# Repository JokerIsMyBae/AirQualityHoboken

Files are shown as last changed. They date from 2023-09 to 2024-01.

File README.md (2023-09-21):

# AirQualityHoboken
Applied IoT project voor luchtkwaliteitsmetingen in Hobokense Polder

### Doel
Meten van specifieke luchtkwaliteitsparameters:
- CO2
- TVOC
- NOx
- Fijnstof
- Temperatuur
- Luchtvochtigheid
- Luchtdruk

### To-Do:
- Bouwen van een sensorbord
- Meten van specifieke luchtkwaliteitsparameters
- Werkt op batterij & PV-cel
- Locatie via GPS
- PCB
- Communicatie via LoRaWAN
- Langdurige test op statische plaatsen Hoboken
- Data opslagen in een DB

### Deliverables
- Robuuste werkende schakeling
- Versie voor Hoboken / light-weight autonome versie voor PoAB
- Sensorbord, modulair, met LoRaWAN module
- 2 testversies op de campus
- 10 definitieve versies

### Deliverables
- Implementatie in Hoboken op statische plaatsen
- Implementatie in de haven op statische plaatsen
- Implementatie in op een drone
- Communicatie via LoRaWAN
- Visualisatie van data via NodeRed - Grafana
- PCB
- Documentatie
- Film

References:
- Power delivery (DFRobot + solar panels)
  https://github.com/Verbeast2K/zanzi-doc/tree/master/sensorbox
- Other parts
  https://github.com/Jappie3/zanzi-doc

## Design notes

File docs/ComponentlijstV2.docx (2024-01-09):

Componentenlijst

benodigdheden voor Lucht kwaliteit meting Hoboken

Component | # nummer | Link | Aantal
LoRa Chip | esp32 | SX1276 | https://jlcpcb.com/partdetail/Dreamlnk-DL_RFM95868M/C2844472 | 5
Esp32 MCU | ESP32-WROOM-32-N8 | https://jlcpcb.com/partdetail/EspressifSystems-ESP32_WROOM_32N8/C529582 | 5
Voltage regulator | LD1117S33TR | https://jlcpcb.com/partdetail/Stmicroelectronics-LD1117S33TR/C86781 | 5
USB --> UART | CP2102N | https://jlcpcb.com/parts/componentSearch?searchTxt=CP2102N | 5
UFL - connector | 0734120110 | https://www.digikey.be/en/products/detail/molex/0734120110/1894611 | 5
Antenne LoRa 868MHz | | https://www.digikey.be/nl/products/detail/pycom-ltd./SIGFOX%2FLORA%2520ANTENNA%2520KIT/7721843?productid=7721843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 | 5
Zonnepaneel | 110X80 | Aanwezig op school | 10
Solar power manager | DF robot | DFR0559 | https://www.dfrobot.com/product-1712.html + stand offs | 5
Batterij 3,7V | 45F2232 | https://www.sossolutions.nl/lithium-ion-batterij-3-7v-1200mah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 | 5
Kabel – 2 draads | (E1052S.41.10) EN50306-3-RAIL-2X0.75 | (https://www.digikey.be/nl/products/detail/prysmian-group/E1052S-41-10/618558) https://www.digikey.be/nl/products/detail/te-connectivity-raychem-cable-protection/EN50306-3-RAIL-2X0-75/13590732 | 2m
Milieu sensor | SEN55 | https://www.sensirion.com/products/catalog/SEN55 | 5
JST connector SEN55 | BM06B-GHS-TBT | https://www.digikey.nl/nl/products/detail/jst-sales-america-inc/BM06B-GHS-TBT-LF-SN-N/807850 https://jlcpcb.com/partdetail/207057-BM06B_GHS_TBT_LF_SN_N/C189892 | 5
Stikstof sensor | SGP41 | https://sensirion.com/products/catalog/SGP41 https://jlcpcb.com/partdetail/Sensirion-SGP41_DR4/C9900005629 | 5
JST connectie kabel | JST GH6 | https://www.adafruit.com/product/5754 | 5
Wartel (voor zonnepaneel kabel) | 12002100 | https://be.farnell.com/bopla/12002100/metric-cable-gland-mbf-m12-x-1/dp/3216813 | 5
Installatie doos | Z74H | https://www.tinytronics.nl/shop/en/tools-and-mounting/enclosures/universal/kradex-enclosure-176x126x57mm-ip65-red-transparent-z74h | 5
Backplate | | Zelf maken | 5
Standoffs | | | 40
Testboard | ESP32-dev-board | https://www.tinytronics.nl/shop/en/development-boards/microcontroller-boards/with-wi-fi/esp32-wifi-and-bluetooth-board-cp2102

Legende:

- PCB
- Voeding
- Behuizing
- Sensoren

Nog te bestellen:

- 4X SEN55
- 5X SEN55 JST connectie kabel
- 5X Wartel
- 2m Kabel – 2 draad
- 4 X behuizing

# Gateway

https://github.com/Jappie3/zanzi-doc/blob/master/gateway/BOM.md

The gateway board uses a CM4-POE-UPS-BASE KIT board as base with a Raspberry PI 4 Compute module. This board has a buildin UPS which uses 3 18650 Li-ion batteries, furthermore the board can be powered from POE (802.3af).

BOM

CM4-POE-UPS-BASE KIT (https://www.waveshare.com/wiki/CM4-POE-UPS-BASE)

3X 18650 batteries

Raspberry PI Compute module 4 with 32GB MMC (CM4104032) (https://datasheets.raspberrypi.com/cm4/cm4-product-brief.pdf)

Antennas voor LoRaWAN

2x Pigtail SMA-MHF

CR2032 batterij

USB SDR + antenna

IC880A LoRaWAN board (https://wireless-solutions.de/products/lora-solutions-by-imst/radio-modules/ic880a-spi/)

Adapter bord IC880A (see below)

Metal housing (https://benl.rs-online.com/web/p/wall-boxes/7755808)

Metal Housing adapter, lasercut from custom design housing_adapter.dxf (https://github.com/Verbeast2K/zanzi-doc/blob/master/gateway/housing_adapter.dxf)

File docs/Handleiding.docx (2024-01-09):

# Handleiding: Hobokense Polder luchtkwaliteit dashboard

# Inleiding

Hieronder vind je de handleiding hoe je het dashboard van de Hobokense Polder kan gebruiken. Als dashboard platform gebruiken we Grafana deze is toegankelijk op de volgende URL: http://npunt.iot-ap.be/. Deze website is beveiligd met een account.

# Kennismaking Grafana

Als je voor het eerst naar http://npunt.iot-ap.be/ surft zal hij jou voor gebruikers gegevens vragen, Vul deze in

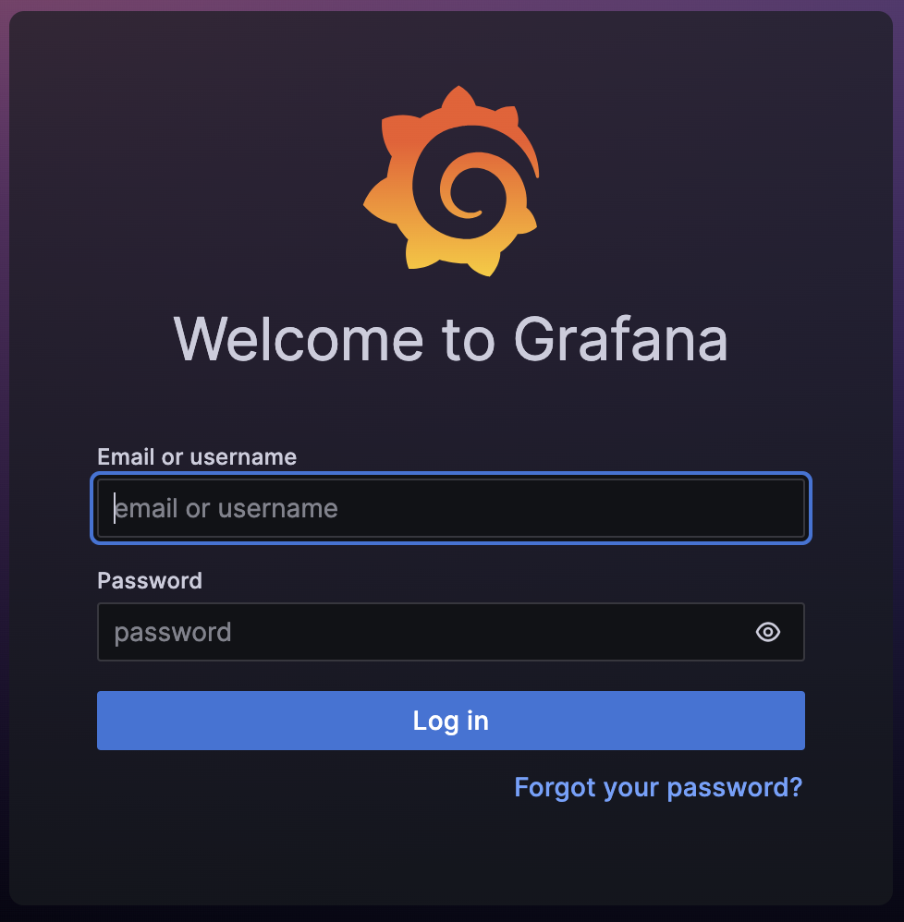
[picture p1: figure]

Dan zal je naar de hoofdpagina van Grafana gestuurd worden. Selecteer hier het dashboard “Hobokense Polder”.

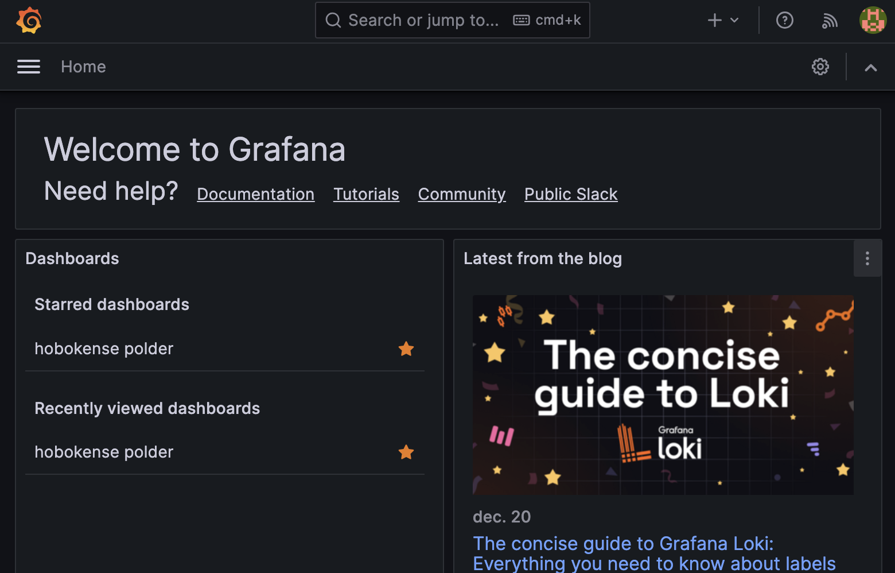
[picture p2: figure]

## Dashboard

A)

B)

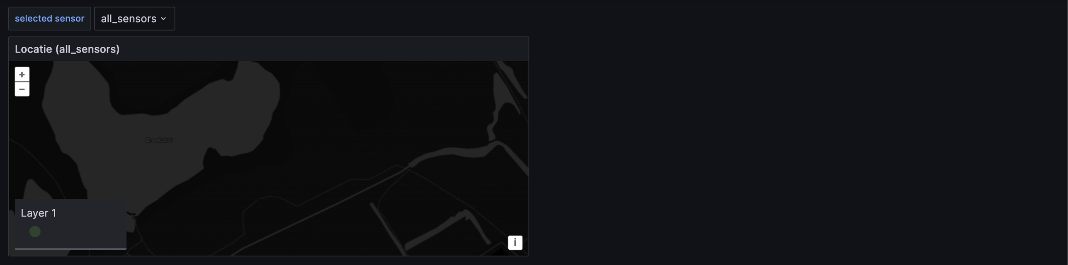
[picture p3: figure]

C)

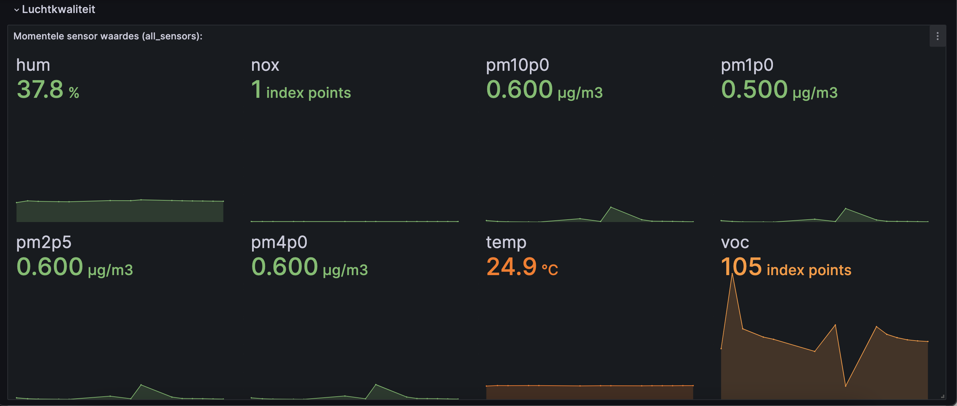
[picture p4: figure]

D)

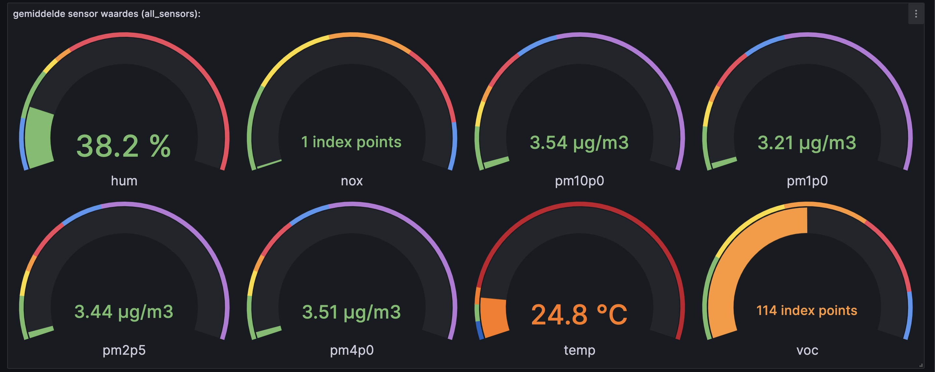
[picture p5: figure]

E)

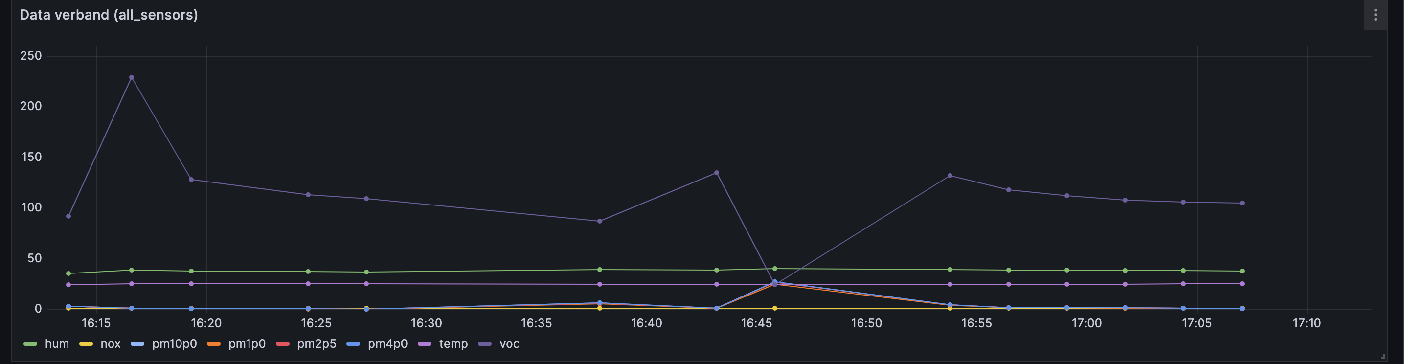
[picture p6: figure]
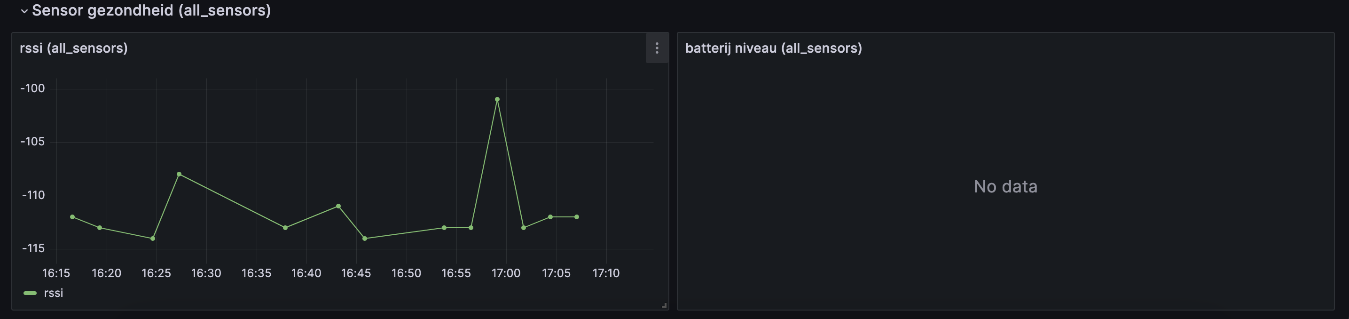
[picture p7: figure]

G)

F)

Uitleg panelen:

a) Linksboven zie je een drop down menu waaruit je kan kiezen welk sensor je wilt gaan bestuderen (dit zijn alle sensoren die zich in de database bevinden) ook kan je de optie “all_sensors” kiezen, het gehele dashboard zal aangepast worden aan de waarde van jouw keuze.
b) Ook vind je van boven een kaart terug, deze geeft de locatie van de sensor weer (of in het geval van “all_sensor” keuze geeft deze alle locaties weer van alle sensoren). De locatie wordt gekozen afhankelijk van welke statisch locatie je hebt opgegeven in de thethingsnetwork op de sensor. (Applications > AirQualityHoboken > End Device > (sensor) > location

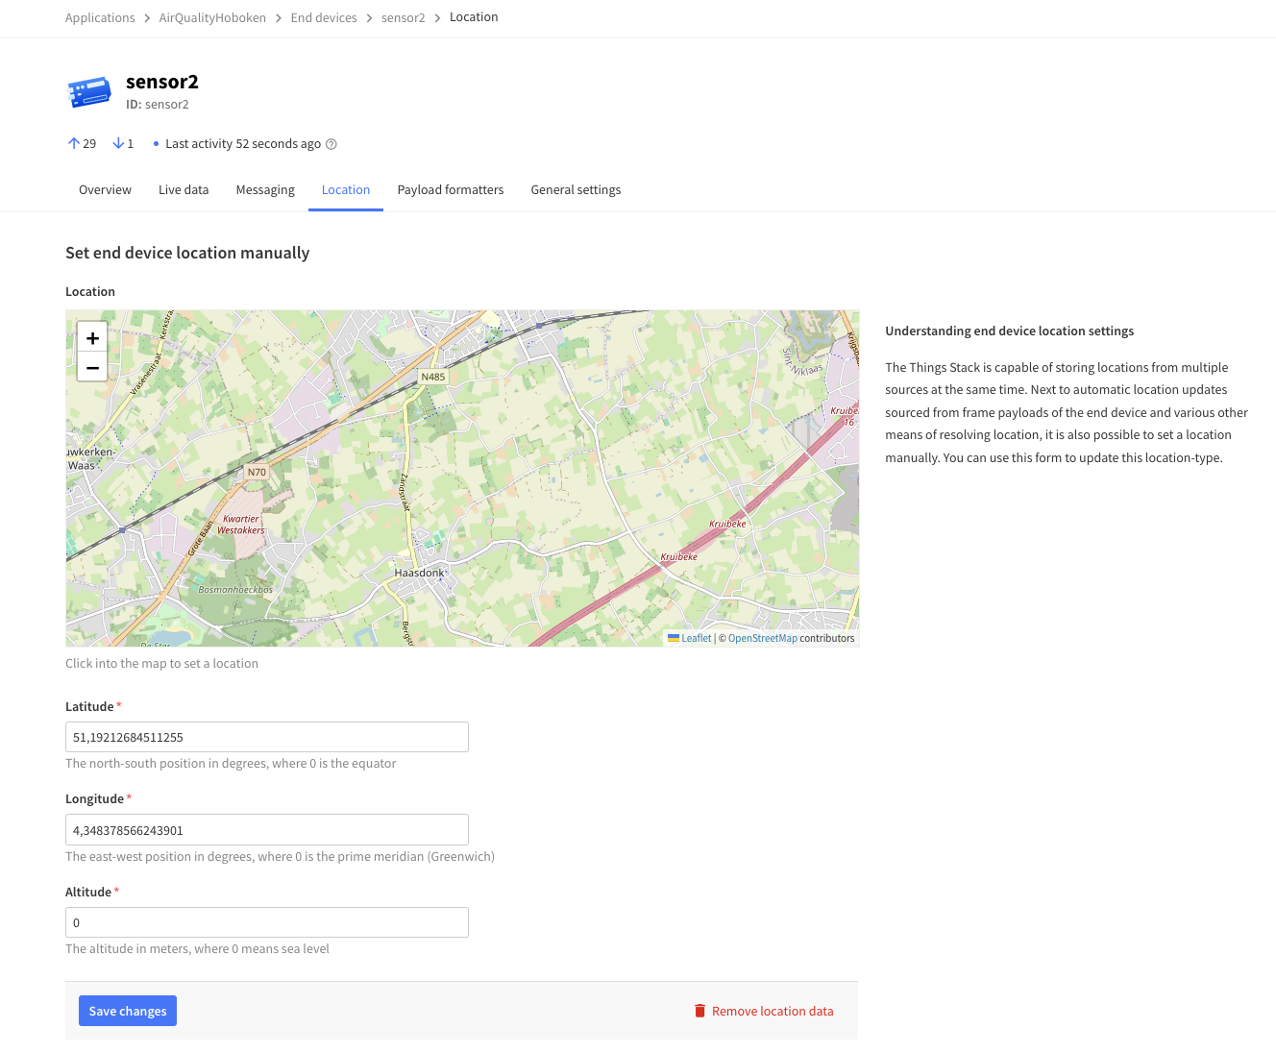
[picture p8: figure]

c) Dit paneel met grafiek geeft de laatste actuele sensor waarde weer van elke sensor ook geeft deze een kleine history weer (deze history is afhankelijk van welke time range je hebt opgegeven).

De time range kan je helemaal boven aan aanpassen

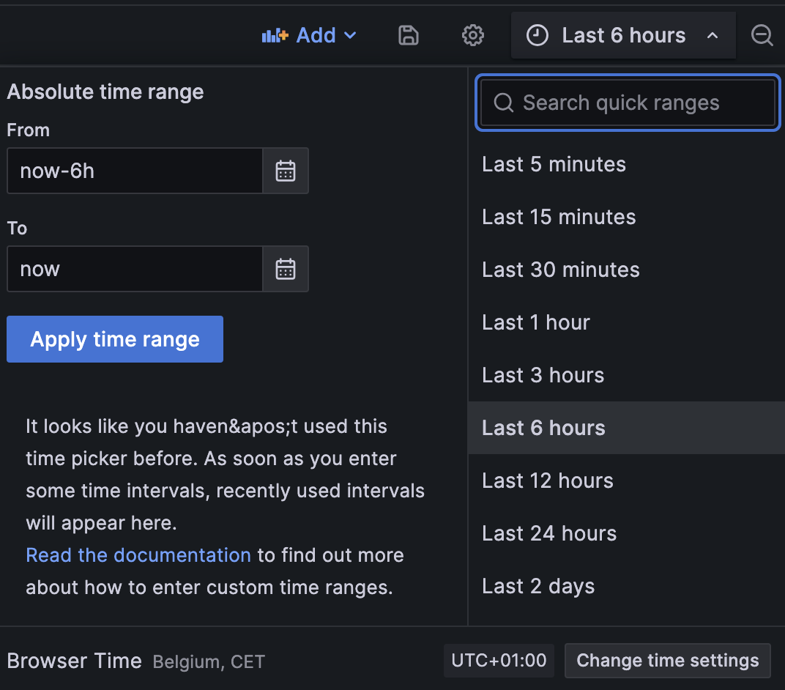
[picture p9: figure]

d) Dit paneel geeft de gemiddelde sensor waardes weer af alle data die zich in de timeline bevindt. Dit betekent dus als je gemiddelde tempratuur wilt weten van de afgelopen 24h stel je de timeline in op “last 24 hours”.

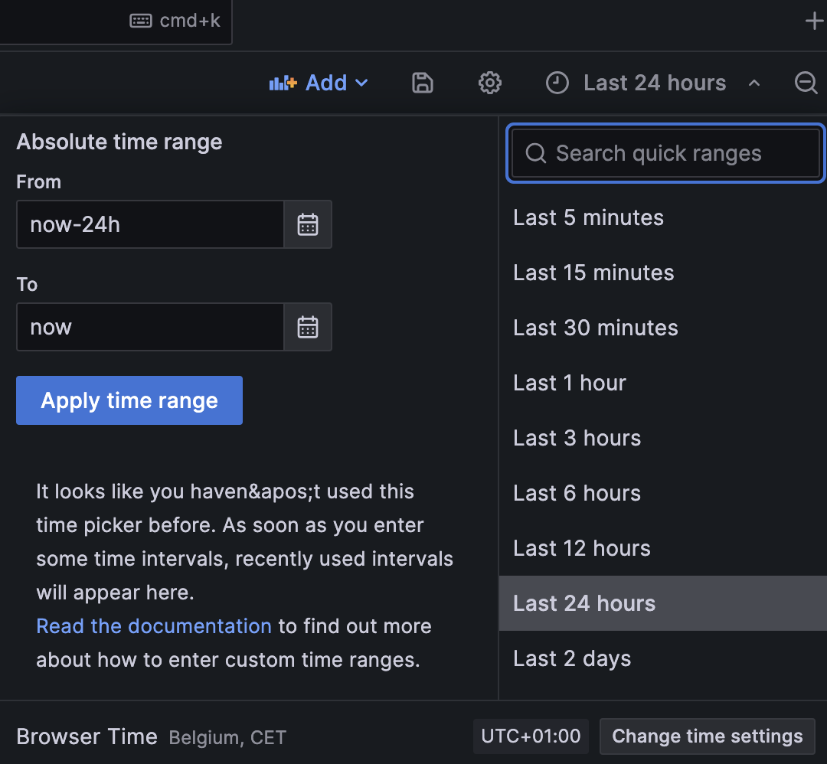
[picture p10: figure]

e) In dit paneel kan je de verbanden tussen verschillende sensor waardes weergeven. Ook hier is deze timeline afhankelijk
f) Dit paneel geeft een grafiek weer over de rssi, met andere woorden hoe sterk de verbinding is tussen sensor kast en LoraWan-gateway. Hoe lager dit getal bij 0 zit hoe beter. Deze geeft dus geen informatie weer over de luchtkwaliteit. Ook hier is deze timeline afhankelijk.
g) Dit paneel geeft de batterij capaciteit weer van de sensor kast. Door tijdsgebrek is deze functie op de sensor kast niet afgeraakt.

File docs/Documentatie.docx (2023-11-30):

# Documentatie

# Hardware | sensoren & PCB

## Sensoren | SEN55 & SPG 41

### SEN55:

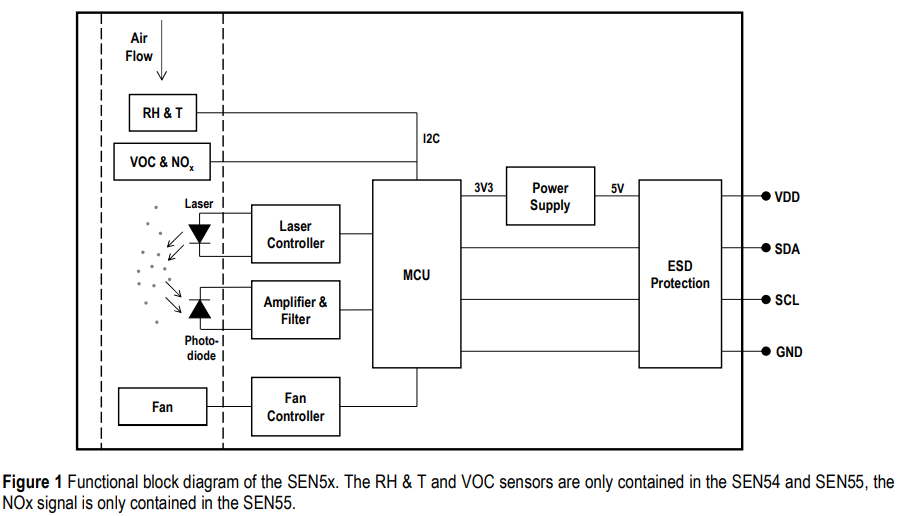
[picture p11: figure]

De SEN55 is een eenvoudig, alles-in-één platform voor sensoroplossingen voor het nauwkeurig meten van verschillende omgevingsparameters, zoals fijnstof, vluchtige organische stoffen (VOC's), oxiderende gassen, zoals stikstofoxiden (NOx), en als vochtigheid en temperatuur.

Over het algemeen kunnen de meeteenheden als volgt zijn:

- Fijnstof: Gemeten in microgram per kubieke meter (µg/m³) voor de concentratie van fijnstofdeeltjes in de lucht.
- VOC's: Gemeten in ppb (parts per billion) of ppm (parts per million) voor de concentratie van vluchtige organische stoffen in de lucht.
- NOx: Gemeten in ppb of ppm voor de concentratie van stikstofoxiden (NOx) in de lucht.
- Vochtigheid: Gemeten in procent (%), wat de relatieve luchtvochtigheid weergeeft.
- Temperatuur: Gemeten in graden Celsius (°C) voor de temperatuur in de omgeving.

De exacte eenheden en meetbereiken kunnen variëren afhankelijk van de specifieke sensoren en configuraties die worden gebruikt binnen het SEN55-platform van Sensirion.

### SPG 41:

De SGP41 is een VOC- en NOx-sensor van Sensirion. Deze sensor is zeer geschikt voor het voortdurend monitoren van de VOC- en NOx-situatie, inclusief potentieel schadelijke gebeurtenissen die niet door mensen worden waargenomen.

De meeteenheid voor VOC kan in het algemeen worden uitgedrukt in parts per billion (ppb) of parts per million (ppm), afhankelijk van de concentratie van vluchtige organische stoffen. NOx-concentraties worden meestal uitgedrukt in ppb of ppm voor gassen zoals stikstofdioxide (NO2) en stikstofmonoxide (NO). De precieze meeteenheden kunnen variëren afhankelijk van de specifieke configuratie en toepassing van de sensor.

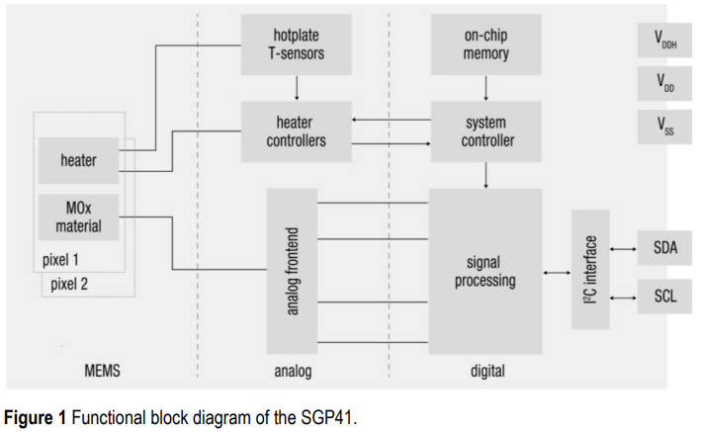
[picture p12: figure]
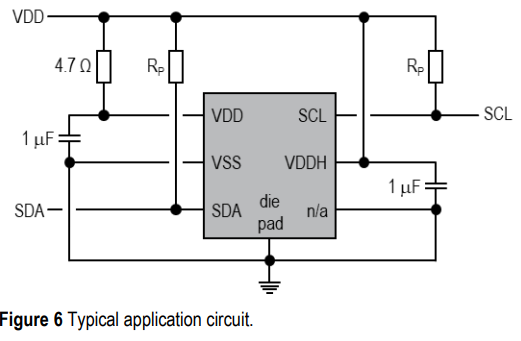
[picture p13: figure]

## PCB

### 1ste versie

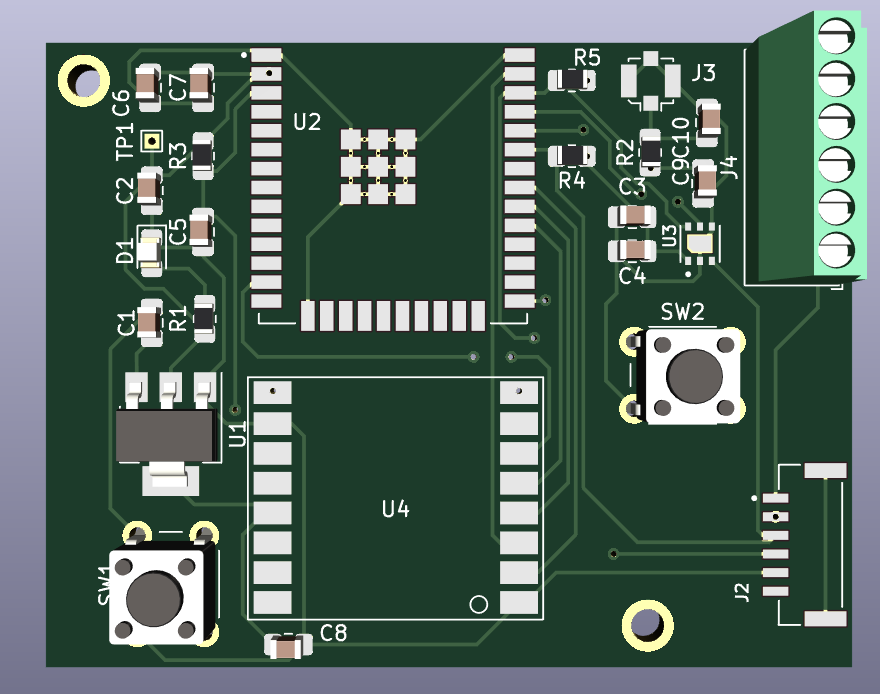
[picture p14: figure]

Front

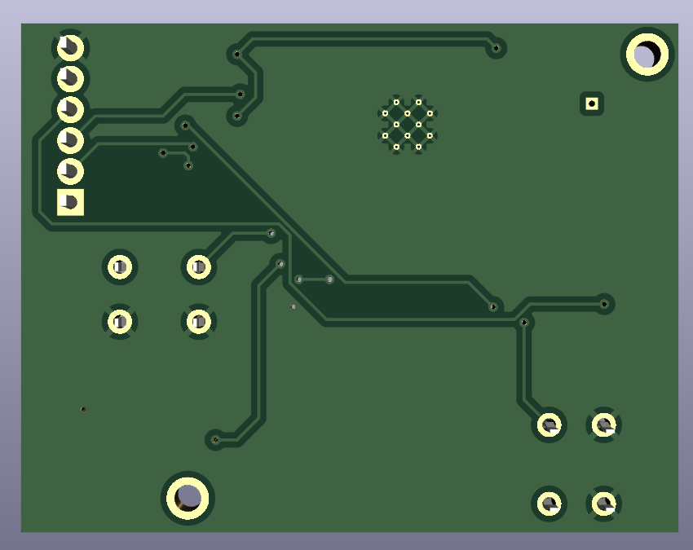
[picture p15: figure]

Back

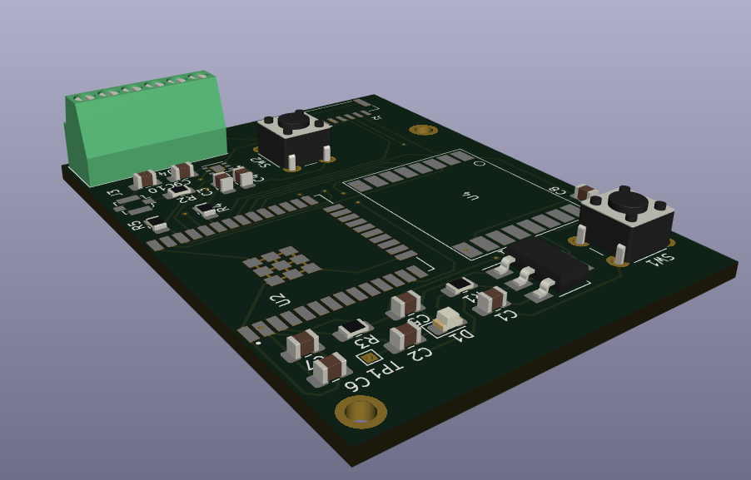
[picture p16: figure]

Isometrische projectie

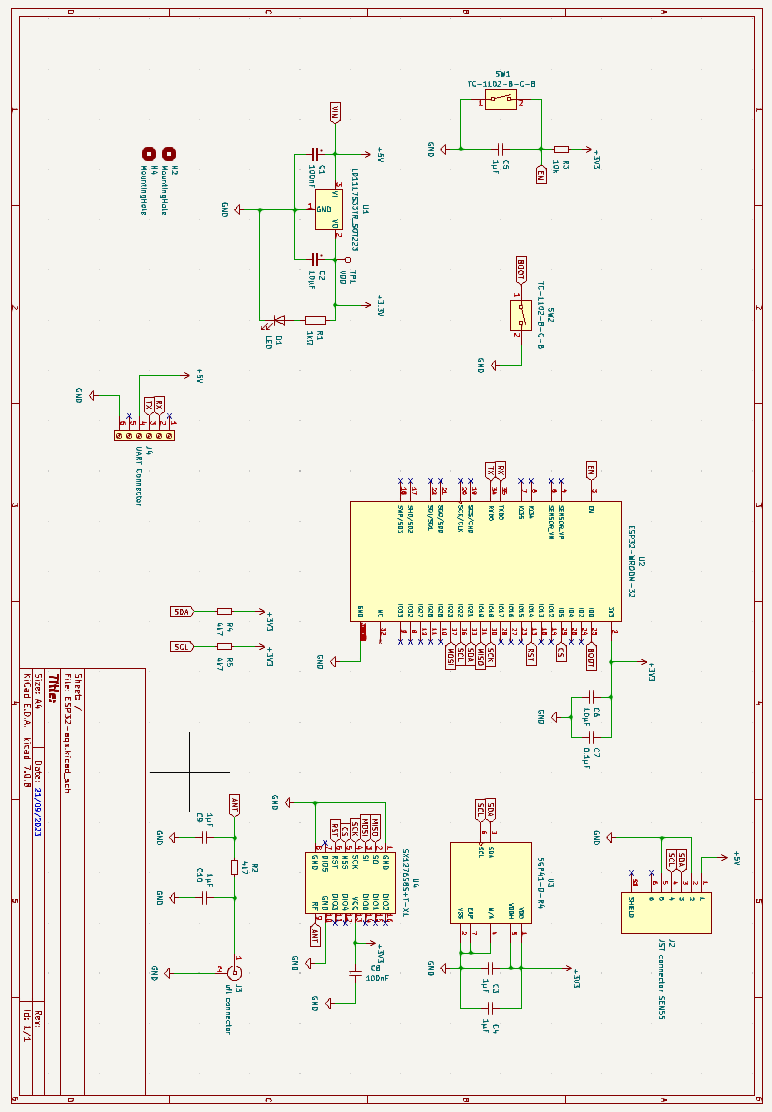
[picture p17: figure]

Uitleg pcb:

We dienden rekening te houden met verschillende aspecten, waaronder de dikte van onze PCB-lijnen in relatie tot het stroomverbruik. We hebben eerst het maximale stroomverbruik berekend en deze verdubbeld. Met behulp van een PCB Trace Width Calculator hebben we parameters zoals stroomverbruik, normale temperatuur, stijgende temperatuur en dikte ingevoerd. Uit de berekeningen bleek dat de lijndikte minimaal 0.03 mm moest zijn. De standaarddikte die we in KiCad gebruiken is 0.25 mm, wat ruim voldoende is.

Bij de plaatsing van de ESP32-chip moesten we ervoor zorgen dat de antenne niet tussen andere componenten lag. Dit hebben we opgelost door de antenne iets buiten het bord te laten steken. Daarnaast was het belangrijk om ervoor te zorgen dat de connectoren aan de zijkant waren geplaatst om een optimale verbinding te garanderen.

BoM

# Layout en design (enclosure)

Backplate:

Aangezien we alles gemakkelijk willen monteren hebben we gekozen om een backplate te monteren in onze installatie doos. Dit maakt zo wel ontwikkeling en installatie handiger. Alle componenten worden individueel gemonteerd op deze backplate doormiddel van standoffs:

- PCB
- Antenne
- Batterij
- SEN55 (temp, hum, VOc, NOc, fijnstof sensor)

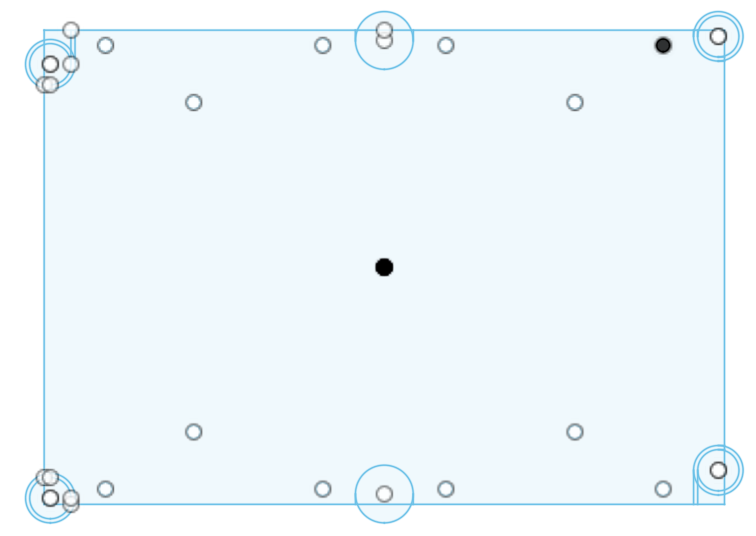
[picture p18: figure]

## Dak:

Aangezien vandalisme en het verstoren van de natuurlijk een belangrijk topic is voor natuurpunt. Hebben we dus beslist om de sensoren op een bepaalde hoogte te hangen (bijvoorbeeld in een boom). Aangezien we niet een lelijke installatie doos in een boom willen hangen willen we deze dus camoufleren in de natuur, hierdoor hebben we gekozen om de installatie doos meer te doen lijken op een nestkastje. Dit gaan we doen door een 3D print te ontwikkelen die als punt dak zal gemonteerd worden op de bovenkant van de installatie doos. Voordeel hiervan is dat we ook een plaats hebben om onze zonnepanelen te monteren.

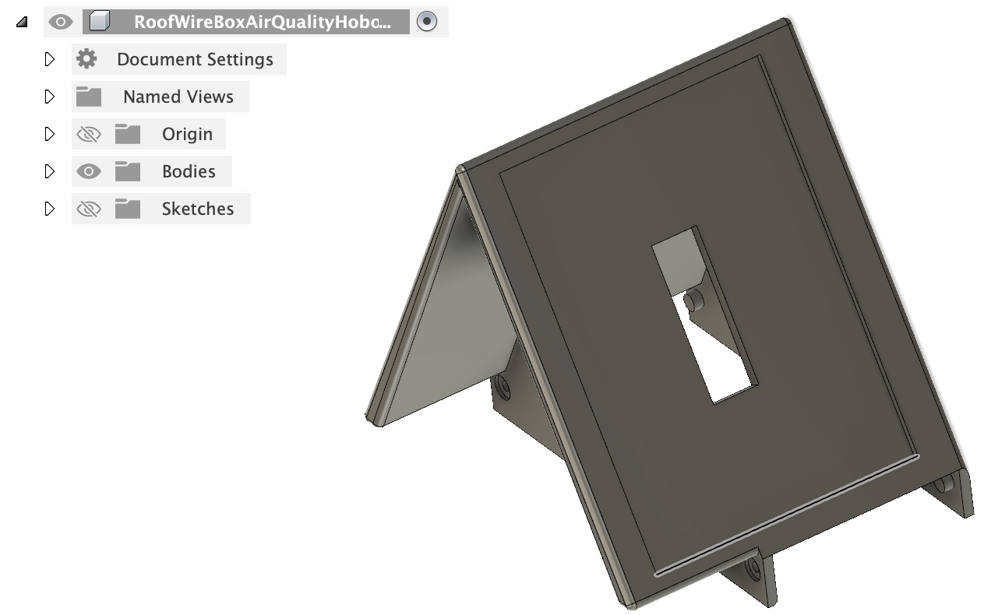
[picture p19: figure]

# TheThingsNetwork | LoRaWAN

## TheThingsNetwork

### Wat is de TheThingsNetwork:

TheThingsNetwork (TTN) is een open source en door de gemeenschap gedreven project dat tot doel heeft een wereldwijd, crowd-sourced en gedecentraliseerd Internet of Things (IoT)-netwerk te creëren. Het biedt de infrastructuur en tools die nodig zijn om een LoRaWAN (Long Range Wide Area Network) voor IoT-apparaten te bouwen en te exploiteren. TTN is gebaseerd op LoRaWAN-technologie en wordt onderhouden door vrijwilligers en gemeenschappen. Het stelt bedrijven en ontwikkelaars in staat om IoT-oplossingen te bouwen boven op dit netwerk.

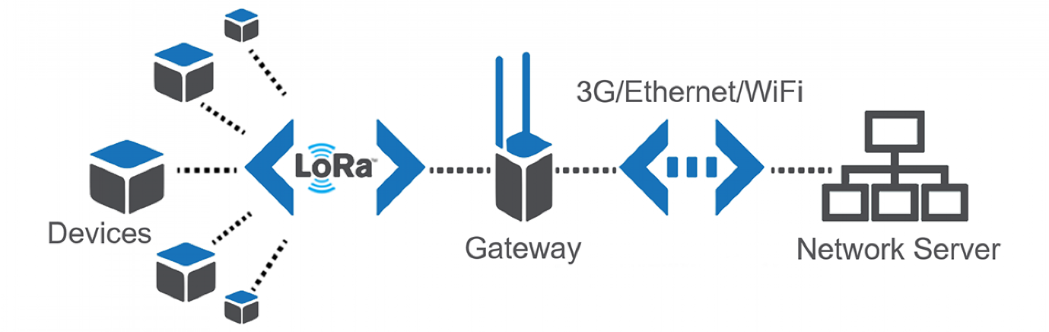
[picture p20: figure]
LoraWan | antennas and accessories

Figuur 1 Data overdracht sensor naar TTN

### Hoe werkt TTN:

Na het creëren van een end device en het genereren van de unieke sleutels en ID, volgt het volgende proces:

End Device Communicatie: Het end device, zoals een IoT-sensor of -apparaat, verzendt gegevens die het wil overdragen via het LoRaWAN-protocol.

Data Verpakt: De gegevens worden verpakt in LoRaWAN-pakketten, die de ID van het end device bevatten, evenals de beveiligingssleutels die nodig zijn voor de codering en beveiliging van de gegevens.

Verzending naar de Gateway: De LoRaWAN-pakketten worden via radiofrequentie verzonden naar een nabijgelegen gateway, die fungeert als een ontvangststation. Gateways kunnen overal in de omgeving zijn geïnstalleerd en kunnen de gegevens van meerdere end devices ontvangen.

Gateway naar Netwerk Server: De gateway ontvangt de pakketten, decodeert de gegevens en stuurt deze door naar een TTN-netwerkserver via een internetverbinding.

Netwerkserver: De TTN-netwerkserver ontvangt de gegevens van de gateway en is verantwoordelijk voor het routeren van de gegevens naar de juiste bestemming. Het verifieert ook de beveiligingssleutels om de integriteit en beveiliging van de gegevens te waarborgen.

Applicatie Server: De gegevens worden doorgestuurd naar een applicatieserver die specifiek is opgezet voor de toepassing of service waarmee de gegevens worden gebruikt. Deze server verwerkt en analyseert de gegevens en voert de nodige acties uit, zoals opslag, visualisatie of het triggeren van meldingen.

Terugkerende Communicatie: Als bidirectionele communicatie is vereist, kan de applicatieserver gegevens naar het end device sturen via dezelfde route, waarbij de server de gegevens naar de juiste gateway en uiteindelijk naar het end device routeert.

Beheer en Monitoring: TTN biedt beheer- en monitoringstools waarmee gebruikers de prestaties van hun netwerk kunnen volgen, apparaat registraties kunnen beheren en beveiligingsinstellingen kunnen configureren.

### Stappenplan:

1) Maak een applicatie aan.
2) Voeg een end device toe met volgende instellingen.
3) Genereer alle sleutels (keys).

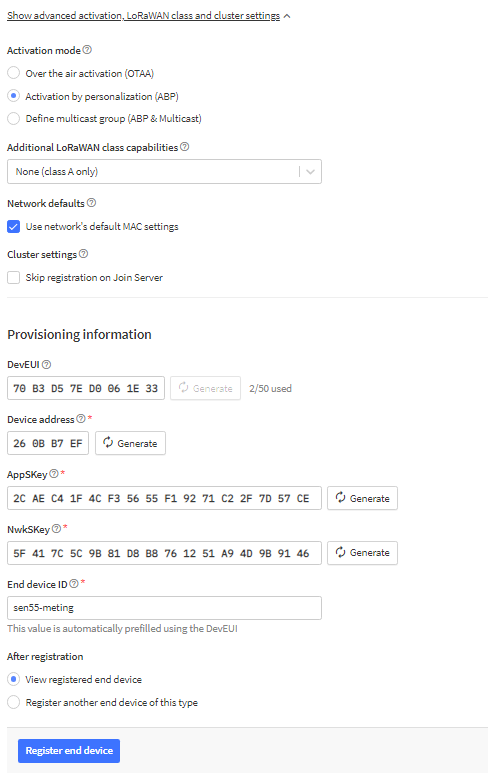
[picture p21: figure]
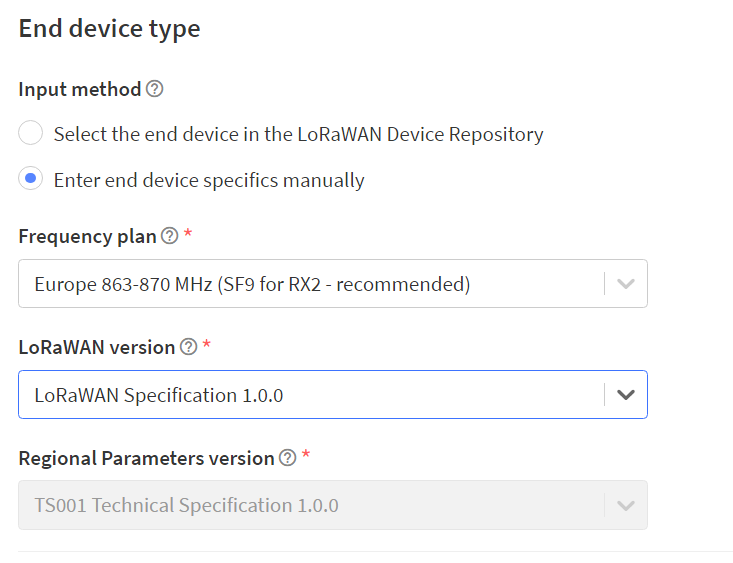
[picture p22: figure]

EXTRA! Bij ABP ga naar general setting < Network layer < advanced MAC settings < Reset frame counters

Dit zorgt ervoor dat dezelfde sensor herkend wordt nadat deze uit is getrokken en later terug gebruikt moet worden.

4) Voeg nu de nodige keys toe aan de credentials in de code voor de sensor.

/* Credentials file */

#pragma once

// Only one of these settings must be defined

#define USE_ABP

//#define USE_OTAA

#ifdef USE_ABP

// LoRaWAN NwkSKey, network session key

static const u1_t PROGMEM NWKSKEY[16] = { Voeg hier de NWSKEY toe };

// LoRaWAN AppSKey, application session key

static const u1_t PROGMEM APPSKEY[16] = { Voeg hier de APPSKEY toe };

// LoRaWAN end-device address (DevAddr)

// This has to be unique for every node

static const u4_t DEVADDR = 0xVoeg hier de DEVADDR toe;

#endif

5) Upload de code met de gewenste sensor code.
6) Payload Formatter < Uplink voor het decoderen van bytes. (Voorbeeld voor SPG41)

SPG41

function Decoder(bytes, port) {

var decoded = {};

decoded.VOC = (bytes[0] << 8) + bytes[1];

decoded.NOX= (bytes[2] << 8) + bytes[3];

return decoded;

}

SEN55

function Decoder(bytes, port) {

var decoded = {};

decoded.pm1p0 = (bytes[0] << 8) + bytes[1] /100;

decoded.pm2p5= (bytes[2] << 8) + bytes[3] /100;

decoded.pm4p0= (bytes[4] << 8) + bytes[5] /100;

decoded.pm10p0= (bytes[6] << 8) + bytes[7] /100;

decoded.hum= (bytes[8] << 8) + bytes[9] /100;

decoded.temp= (((bytes[10] << 8) + bytes[11]) /100) -10;

decoded.voc= (bytes[12] << 8) + bytes[13] /100;

decoded.nox= (bytes[14] << 8) + bytes[15] /100;

return decoded;

}

## LoRaWAN

### Wat is LoRaWAN:

LoRaWAN is een draadloos communicatieprotocol dat is ontworpen voor lange afstandsconnectiviteit van batterij gevoede IoT-apparaten. Het biedt een groot bereik, laag energieverbruik en wordt veel gebruikt in toepassingen zoals smart cities en industriële automatisering. Het is een open standaard en kan zowel publieke als private netwerken omvatten.

### Specificaties:

De specificaties van LoRaWAN (Long Range Wide Area Network) omvatten de volgende belangrijke kenmerken:

- Frequentiebanden: LoRaWAN werkt op de 868 MHz-band in Europa.
- Lange Afstand: Het biedt connectiviteit over lange afstanden, variërend van enkele kilometers tot tientallen kilometers, afhankelijk van de omgeving en de frequentieband.
- Laag Energieverbruik: LoRaWAN is ontworpen voor energiezuinigheid, waardoor batterij gevoede IoT-apparaten maanden tot jaren op een enkele batterij kunnen werken.
- Bij schaalbaarheid: LoRaWAN-netwerken hebben meestal een gelaagde structuur die schaalbaarheid mogelijk maakt. Dit omvat eindapparaten (devices), gateways en een netwerkserver.
- Adaptieve Modulatie: LoRaWAN past de modulatie aan op basis van de afstand en omgevingsomstandigheden, waardoor het betrouwbaarheid en prestaties levert over variabele afstanden.
- Bidirectionele Communicatie: Het ondersteunt tweerichtingscommunicatie, waarbij apparaten gegevens kunnen verzenden en ontvangen via LoRaWAN-netwerken.
- Beveiliging: LoRaWAN bevat beveiligingsmaatregelen om gegevens te beschermen, waaronder encryptie van gegevens en apparaat authenticatie.
- Open Standaard: LoRaWAN is een open standaard, wat betekent dat het niet afhankelijk is van een specifieke fabrikant en interoperabiliteit tussen verschillende apparaten mogelijk maakt.
- Join Procedure: Apparaten moeten zich aanmelden bij een LoRaWAN-netwerk voordat ze gegevens kunnen verzenden of ontvangen. Dit wordt doorgaans gedaan via een join procedure.
- Publieke en Private Netwerken: LoRaWAN-netwerken kunnen zowel publiek als privaat zijn, afhankelijk van de toepassing en de beheerder.

# Opzetten van de server (back-end)

## Wat hebben we nodig:

Voor de back-end van ons project maken we gebruik van drie essentiële services:

Node-Red: Deze service wordt ingezet om gegevens op te halen van TheThingsNetwork, deze te verwerken en vervolgens in de 'InfluxDB' database te integreren.

InfluxDB: We gebruiken InfluxDB als onze database-oplossing. Hierin worden de gegevens opgeslagen die we verzamelen en verwerken met Node-Red.

Grafana: Om de verzamelde gegevens op een visueel aantrekkelijke manier te presenteren, vertrouwen we op Grafana. Met Grafana kunnen we de gegevens in onze Influx-database grafisch weergeven.

Deze combinatie van services stelt ons in staat om gegevens efficiënt te verzamelen, verwerken en presenteren in ons project

## Docker:

We hebben besloten om deze drie services binnen een Linux-omgeving op te zetten met behulp van containers. Het gebruik van containers biedt tal van voordelen, waaronder aanzienlijke flexibiliteit en een hoge mate van veiligheid. Containers zijn namelijk geïsoleerd van elkaar, wat betekent dat elke service in zijn eigen afzonderlijke omgeving opereert. Dit zorgt ervoor dat eventuele problemen of wijzigingen in één container de andere containers niet beïnvloeden. Bovendien maakt het opzetten van services in containers het proces van ontwikkelen, testen en implementeren aanzienlijk efficiënter en schaalbaarder.

## Docker netwerk

Om effectieve communicatie tussen de Docker-containers mogelijk te maken, is het essentieel dat ze zich binnen hetzelfde Docker-netwerk bevinden. Dit zorgt ervoor dat de containers naadloos met elkaar kunnen communiceren en gegevens kunnen uitwisselen. Door ze in hetzelfde netwerk te groeperen, kunnen we ervoor zorgen dat de services en applicaties die deze containers hosten, moeiteloos en efficiënt met elkaar kunnen samenwerken, waardoor de algehele systeemprestaties worden geoptimaliseerd.

Opzetten:

1. Zet een linux server op (bij voorkeur --> debian)
2. Installeer zowel docker als docker-compose
3. Maak een folder aan (met naam naar keuze) en cd in deze folder
4. Zet deze ‘docker-compose.yml’ op de linux server in de folder die je in vorige stap hebt gemaakt:

version: "3.8"

services:

node-red:

container_name: node-red-air-quality-hoboken

image: nodered/node-red:latest

restart: unless-stopped

environment:

- TZ=Europe/Brussels

ports:

- '1880:1880'

networks:

- air-quality-hoboken

volumes:

-./node-red-data:/data

grafana:

container_name: grafana-air-quality-hoboken

image: grafana/grafana:latest

restart: unless-stopped

environment:

- TZ=Europe/Brussels

ports:

- '3000:3000'

networks:

- air-quality-hoboken

volumes:

- ./grafana-data:/var/lib/grafana

influxdb:

container_name: influx-db-air-quality-hoboken

image: influxdb:latest

networks:

- air-quality-hoboken

security_opt:

- no-new-privileges:true

restart: unless-stopped

ports:

- '8086:8086'

volumes:

- ./influxdb2-data/config:/etc/influxdb2

- ./influxdb2-data/appdata:/var/lib/influxdb2

networks:

air-quality-hoboken:

5. Bouw de docker-containers met behulp van docker-compose: zorgt dat je in de folder bent waar de docker-compose file zich bevindt en voer het volgende commando uit:

docker-compose up -d

6. (Bij errors kan het zijn dat de permissions van de volumes niet goed staan, pas deze aan)
7. Bekijk het docker ip-address van de influxdb aangezien je deze nodig gaat hebben voor de connectie met Node-Red en Grafana:

docker inspect influx-db-air-quality-hoboken

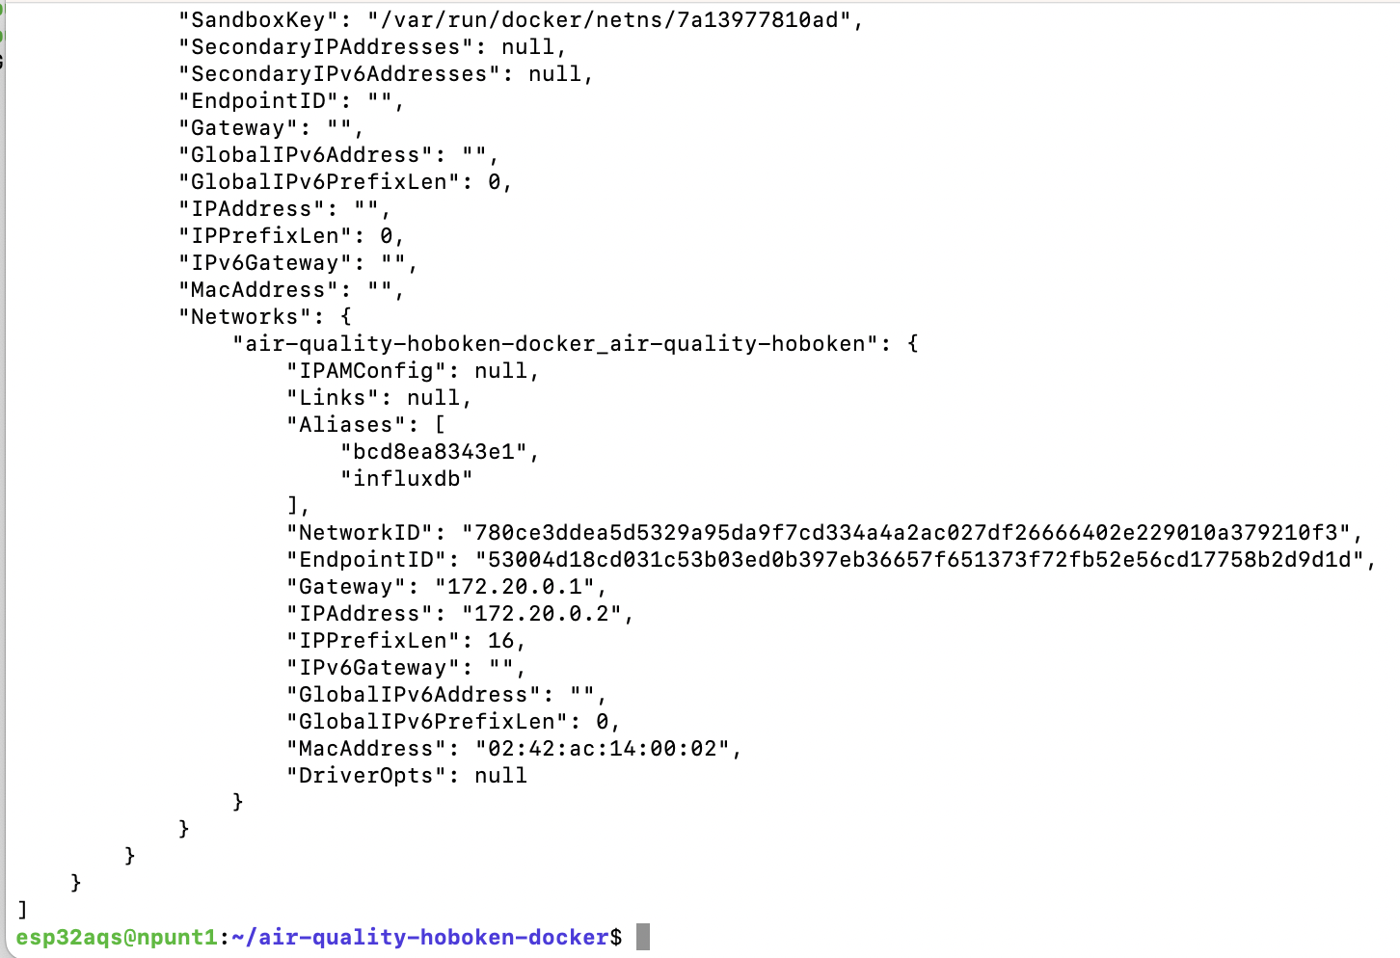
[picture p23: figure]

# Node-Red

### Wat is Node-Red:

Node-RED is een visuele programmeeromgeving waarmee je Internet of Things (IoT) en automatiseringstaken kunt maken en beheren. Het is gebaseerd op knooppunten die je kunt slepen en neerzetten om workflows te bouwen. Deze knooppunten vertegenwoordigen verschillende functies en apparaten en kunnen worden verbonden om gegevens te sturen, verwerken en integreren.

Node-RED is populair vanwege zijn gebruiksvriendelijke interface en flexibiliteit, waardoor het ideaal is voor taken zoals gegevensverwerking, het aansturen van hardware, en het automatiseren van taken in huis of op het werk. Het wordt vaak gebruikt in combinatie met Raspberry Pi en andere IoT-apparaten. Het biedt ondersteuning voor tal van protocollen en services, waardoor je gegevens van verschillende bronnen kunt verzamelen en ermee kunt interageren.

In essentie is Node-RED een tool waarmee je eenvoudig IoT- en automatiserings workflows kunt ontwerpen zonder uitgebreide programmeervaardigheden te hebben.

### Waarom gebruiken wij Node-Red:

Node-RED is een uitstekende keuze voor het stroomlijnen van het proces om gegevens van TheThingsNetwork via MQTT binnen te halen en specifieke waarden uit de JSON-gegevens te filteren voordat deze worden opgeslagen in onze database, INFLUXDB. Node-RED biedt een intuïtieve visuele interface waarmee we gemakkelijk de MQTT-gegevensstroom kunnen vastleggen, de JSON-berichten kunnen analyseren en alleen de relevante informatie kunnen selecteren die we willen bewaren. Het bespaart ons tijd en vereenvoudigt het gegevensverwerkingsproces, waardoor we gegevens efficiënt kunnen opslaan en analyseren in INFLUXDB voor verdere inzichten en acties.

### Schema:

### Blokken:

Instellingen MQTT blok → Bij het aanmaken van een MQTT integration een API key genereren en deze opslaan (deze ga je later nodig hebben als wachtwoord in Node-Red).

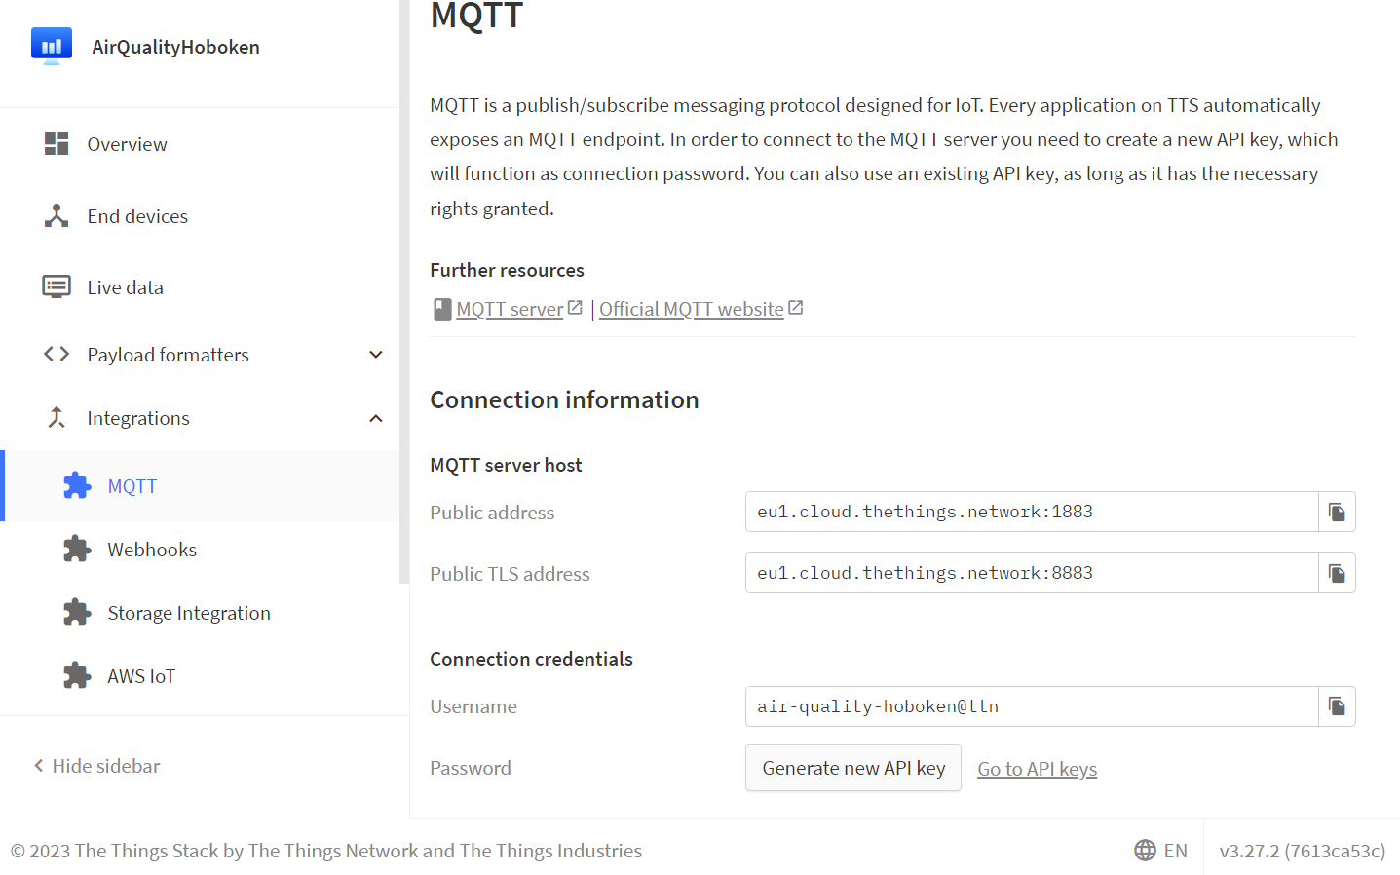
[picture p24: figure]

MQTT node:

- Server: Hier vul je de naam of het IP-adres van de MQTT-broker in, samen met de poort (meestal 1883).
- Action:
  - Subscribe to Single Topic (Abonneren op enkelvoudig topic): Hiermee abonneer je de MQTT-node op een specifiek MQTT-topic dat je vooraf instelt.
  - Dynamic Subscription (Dynamisch abonnement): Hiermee kun je het MQTT-topic dynamisch instellen op basis van informatie in het inkomende bericht. Dit maakt je abonnement flexibel en afhankelijk van de gegevens die je ontvangt.
- Topic: Dit is een tekstlabel waarmee je berichten kunt categoriseren. Abonneer je op het gewenste MQTT-topic voor de juiste data te krijgen.
- QoS: Kies de gewenste kwaliteit van service voor berichten (0, 1 of 2).


Security: Vul de juiste username en wachtwoord in. Dit is de username en wachtwoord (api key) die je in het begin hebt aangemaakt in TTN.


JSON node:

We plaatsen de JSON node voor de inkomende berichten naar een JSON formaat te brengen.

Change node:

Bij deze node zullen we de ontvangen payload omzetten naar een zeer specifiek onderdeel (alleen het gene wat wij willen) van de payload en deze vervolgens doorsturen.


Debug node:

In deze node gaan we de data weergeven in de console.


Influxdb out node:

Hierna gaan we een msg.payload informatie in de database zetten. In de bucket ‘ESP32aqs’, onder measurement ‘Sensordata’.


Het connecteren met de influxdb is eenvoudig!

Je geeft het IP-adres in van de infuxdb docker container (kan je checken met ‘docker inspect influx-db-air-quality-hoboken’ commando). En je zorgt dat je een API-token aanmaakt zoals in topic van influxdb is besproken. Als bucket kies je de bucket (database) die je hebt aangemaakt. Measurement kies je een zelfgekozen waarden kan zijn ‘airqualitysensor1’ zijn.


# Database | Influxdb & docker

Als database voor ons project gebruiken we InfluxDB. InfluxDB is een tijdreeksdatabase die we kunnen gebruiken om IoT sensordata op te slaan.

We kunnen daarna de database beheren en data bekijken via de ingebouwde web interface. We krijgen toegang via de browser op http://localhost:8086/.

In deze web interface moeten we vervolgens een nieuwe gebruiker en wachtwoord aanmaken. We kunnen dan een bucket aanmaken. Een bucket kan je vergelijken met de database waarin onze data zal worden opgeslagen. Wij maken de bucket “ESP32aqs” aan. We krijgen vervolgens ook een API-token te zien. Het is belangrijk dat je deze bewaart want je krijgt deze maar één keer te zien. Als we dit gedaan hebben kunnen we vervolgens inloggen in de database met de juist gemaakte gebruiker.

Als we ingelogd zijn kunnen we in de interface data toevoegen, buckets aanmaken en de data van onze buckets visualiseren.

Een "bucket" in InfluxDB is een container waarin tijdreeksgegevens worden opgeslagen. Buckets kunnen worden geconfigureerd met instellingen zoals hoe lang gegevens worden bewaard (tijdretentiebeleid) en welke verwerking erop wordt toegepast. Ze helpen bij het georganiseerd opslaan en beheren van gegevens.


# Frontend | Grafana

### Wat is Grafana:

Grafana is een open-source datavisualisatie- en monitoringplatform dat wordt gebruikt voor het analyseren en weergeven van gegevens uit verschillende bronnen. Het stelt gebruikers in staat om grafieken, diagrammen en dashboards te maken om inzicht te krijgen in gegevens, zoals systeemprestaties, netwerkstatistieken, sensordata en meer. Grafana kan worden geïntegreerd met verschillende gegevensbronnen, zoals databases, Cloud services en monitoringstools, waardoor het een krachtig instrument is voor het bewaken en analyseren van gegevens in real-time. Wij gaan het gebruiken om gegevens te visualiseren en besluitvorming te ondersteunen.

## Opzetten data source:

Het belangrijkste om eerst te doen is het opzetten van een datasource, grafana gaat natuurlijk ergens zijn data van daan moete halen, hierbij gaan we de grafana dus rechstreeks laten communiceren met de influxDB. En gaan deze dus grafisch weergegeven worden doormiddel van grafana dashboards.

1. Ga naar de webserver van grafana op port 3000.
2. Hierbij druk je op data sources


3. Selecteer dan uiteraard influxDB
4. Vul nu de volgende waardes in
- Kies een naam
- Query Language: Flux
- URL: https://docker-ip-address (kan je achterhalen met ‘docker inspect influx-db-air-quality-hoboken’)
- Basic Auth: off
- Organization: Voel hier organizatie in dieje hebt aangemaakt
- Token: Voer hier de API token van influxdb
- Default bucket: vul hier de bucket die je hebt aangemaakt


Save en test de connectie

## Meetwaardes

Referentie NOx:

In de datasheet van de SEN55 sensor vinden we terug dat NOx wordt gemeten in “index points”. We kunnen waardes meten tussen 1 en 500.


Bron: datasheet p.8 https://sensirion.com/media/documents/6791EFA0/62A1F68F/Sensirion_Datasheet_Environmental_Node_SEN5x.pdf

In de info notes kunnen we de betekenis van deze index terugvinden.

https://sensirion.com/media/documents/9F289B95/6294DFFC/Info_Note_NOx_Index.pdf

De referentie index waarde is 1. Een NOx waarde hoger dan 1 betekent dat er meer NOx gassen aanwezig zijn dan gemiddeld.

Een waarde dicht bij 1 betekent dat er (bijna) geen NOx gassen aanwezig zijn.

Referentie VOC:

De referentie index waarde is 100. Een VOC-waarde hoger dan 100 betekent dat er meer VOC aanwezig zijn dan gemiddeld.

Een waarde minder dan 100 betekent dat er minder VOC aanwezig zijn.

Info note: https://sensirion.com/media/documents/02232963/6294E043/Info_Note_VOC_Index.pdf

Referentie Fijnstof:

https://www.vmm.be/data/fijn-stof

- PM10: fijn stof met een diameter kleiner dan 10 μm (micrometer)
- PM2.5: fijn stof met een diameter kleiner dan 2,5 μm (micrometer)

Op de website van de Vlaamse milieumaatschappij vinden we terug dat volgens de Europese richtlijnen de jaargemiddelde PM2.5 concentratie niet hoger mag zijn dan 25 μg/m3.

Het jaargemiddelde PM10 concentratie mag niet hoger zijn dan 40 μg/m3.

# Bronnen

Algemeen project: https://github.com/JokerIsMyBae/AirQualityHoboken

SEN55 Doc: https://www.sensirion.com/media/documents/6791EFA0/62A1F68F/Sensirion_Datasheet_Environmental_Node_SEN5x.pdf

SPG41 Doc: https://sensirion.com/media/documents/5FE8673C/61E96F50/Sensirion_Gas_Sensors_Datasheet_SGP41.pdf

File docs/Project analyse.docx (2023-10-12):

# Toegepaste Informatica/ Elektronica-ICT

Blueprint luchtkwaliteit Hoboken

Onderdeel van het project

ondersteund door de

AP Hogeschool

en uitgevoerd op en begeleid door het bedrijf

Natuurpunt

Joos Van Esbroeck & Niels Aarts & Gil Struyf & Jurgen Vanpeteghem & Jordy Van Mol

Specialisatie IT & IoT

Begeleider: Maarten Luyts Academiejaar 2023-2024

Mentor: Dirk Van Merode 1e semester

## Figurenlijst

## Opdrachtgever

Projectnaam: IoT project Hoboken

Partner: Natuurpunt

Instelling: AP Hogeschool Antwerpen

## Samenvatting

Natuurpunt wil de luchtkwaliteit van de Hobokense polder in kaart brengen met behulp van sensoren en deze data gebruiken voor het verbeteren van de luchtkwaliteit. Er moeten verschillende factoren van de luchtkwaliteit worden gemeten, zoals CO2, NOX, fijn stof, luchtvochtigheid en temperatuur, en mogelijks zwaveldioxide. Dit moet worden samengebracht in een robuust pakket. Wij zullen dit project uitvoeren door een module te maken met de volgende eigenschappen: we gaan statische sensorborden ontwerpen die op vaste plaatsen in de Hobokense polder worden gemonteerd om de luchtkwaliteit doorheen de polder in kaart te brengen. Deze sensorborden hangen in een waterbestendige behuizing, waar nog wel lucht binnen kan.

## As-Is

Natuurpunt Onderzoekt Milieubelasting in de Hobokense Polder

De Hobokense Polder, gelegen in het prachtige Vlaanderen, is een cruciaal natuurgebied dat wordt gekoesterd door Natuurpunt, een vooraanstaande natuurbehoudsorganisatie. Dit unieke stukje natuur staat bekend om zijn biodiversiteit en schilderachtige schoonheid, maar het wordt helaas bedreigd door de impact van naburige bedrijven op het milieu. Om de gezondheid van dit belangrijke natuurgebied te behouden, heeft Natuurpunt besloten om de mate van vervuiling door buurbedrijven grondig te onderzoeken.

De Hobokense Polder is een waar paradijs voor vogels, planten en andere wilde dieren. Het gebied herbergt zeldzame en bedreigde soorten en is van onschatbare waarde voor wetenschappelijk onderzoek en natuurliefhebbers. Echter, de nabijheid van industriële bedrijven heeft de aandacht gevestigd op mogelijke negatieve gevolgen voor het milieu. Het lozen van afvalstoffen, luchtvervuiling en andere activiteiten kunnen een aanzienlijke impact hebben op dit delicate ecosysteem. Om de impact van de buurbedrijven op de Hobokense Polder nauwkeurig te beoordelen, heeft Natuurpunt een uitgebreid onderzoek gelanceerd. Dit onderzoek zal verschillende aspecten van milieuvervuiling aanpakken, waaronder:

Luchtkwaliteit: Het meten van de luchtkwaliteit in de omgeving om de impact van luchtverontreiniging op het planten- en dierenleven in kaart te brengen.

Meten van specifieke luchtkwaliteitsparameters:

- CO2
- TVOC
- NOX
- Fijnstof
- Temperatuur
- Luchtvochtigheid
- Luchtdruk
- Zwaveldioxide

Dit onderzoek zal niet alleen helpen bij het identificeren van vervuilingsbronnen, maar ook bij het ontwikkelen van beleidsmaatregelen en samenwerking met de bedrijven om de impact op de Hobokense Polder te verminderen. Natuurpunt streeft ernaar de natuurlijke schoonheid van dit gebied te behouden en te beschermen voor toekomstige generaties.

Het is van vitaal belang dat bedrijven en de gemeenschap samenwerken om duurzame oplossingen te vinden die zowel de economische ontwikkeling als de bescherming van de natuur ondersteunen. De inspanningen van Natuurpunt om de Hobokense Polder te behouden en te herstellen zijn een cruciale stap in de richting van een evenwichtige co-existentie tussen de natuur en industrie.

## Situatie To-Be

Doel:

Het doel van dit project is het ontwerpen en bouwen van een geavanceerd sensorbord dat specifieke luchtkwaliteitsparameters kan meten. Het sensorbord moet in staat zijn om autonoom te werken op batterijen en zonne-energie (PV-cel), het moet een PCB (Printed Circuit Board) bevatten voor de sensoren, en de gegevens moeten worden gecommuniceerd via LoRaWAN. Bovendien moet het sensorbord worden ingezet voor langdurige testen op statische locaties in de Hobokense polder en de verzamelde gegevens moeten worden opgeslagen in een database voor verdere analyse.

Beschrijving van de situatie:

Onze organisatie heeft zich ten doel gesteld om de luchtkwaliteit in de Hobokense regio te verbeteren en te bewaken. We hebben een project gestart waarbij we een geavanceerd sensorbord willen ontwikkelen en implementeren om specifieke luchtkwaliteitsparameters te meten, zoals fijnstofniveaus (PM2.5 en PM10), stikstofdioxide (NO2), koolstofmonoxide (CO), ozon (O3) en vluchtige organische stoffen (VOS).

Het sensorbord moet autonoom kunnen werken op batterijen en zonne-energie, wat essentieel is voor langdurige inzet op statische locaties zonder afhankelijk te zijn van het elektriciteitsnet.

De kerncomponent van het sensorbord is een PCB waarop de sensoren zijn gemonteerd en die de metingen verzamelt en verwerkt. De gegevens moeten worden verzonden via het LoRaWAN-netwerk naar een centrale database voor verdere analyse. Dit maakt real-time bewaking en rapportage mogelijk.

Voor het testen en bewaken van de luchtkwaliteit zullen meerdere van deze sensorborden gedurende een langere periode op strategische locaties in de Hobokense polder worden geplaatst. De verzamelde gegevens worden continu opgeslagen in een database, zodat we trends kunnen analyseren, waarschuwingen kunnen activeren bij overschrijding van drempelwaarden en onze inspanningen kunnen richten op gebieden waar luchtkwaliteitsproblemen het meest urgent zijn.

Dit project is van groot belang om de luchtkwaliteit in Hoboken te monitoren en beleidsmaatregelen te nemen om de gezondheid van de gemeenschap te beschermen en de impact op het milieu te verminderen. Het zal een cruciale rol spelen in het verzamelen van gegevens en het nemen van gerichte maatregelen om de luchtkwaliteit te verbeteren.

## Projectdefinitie

Deze ontwikkeling houdt het volgende:

- Bouwen van een sensorbord
- Meten van specifieke luchtkwaliteitsparameters
- Werkt op batterij & PV-cel
- PCB
- Communicatie via LoRaWAN
- Langdurige test op statische plaatsen Hoboken
- Data opslagen in een database
- Ontvangen data visualiseren in een dashboard

## Scope

Fysiek:

- Uitbreiden LoRaWAN netwerk door toevoegen van extra gateway
- Gateway toevoegen aan The Things Network
- Moederbord voor ESP32 en sensoren ontwikkelen met interfaces voor luchtkwaliteitssensoren of vast gemonteerde luchtsensoren
- Werking sensorbord autonoom maken door gebruik van herlaadbare batterij op te laden met pv-panelen
- Behuizing ontwerpen waarin sensorbord past
- Sensoren voorzien
- Sensorborden monteren op vijf vaste locaties in hobokense polder

Softwarematig:

- Data van luchtsensoren op een vast interval verzamelen, en automatisch versturen over LoRaWAN netwerk
- Documentatie over werking sensorbord voorzien
- Energieverbruik beperken door uitschakelen MCU/sensoren wanneer mogelijk

Uitbreiding:

- Toevoegen van zwaveldioxide sensoren voor monitoren aanwezigheid SO2 in de polder

## Niet in scope

- GPS-sensor voor GPS-locatie
- Onderhoud van sensorborden op langere termijn

## Planning

Belangrijke data | Taak | Geschatte duur
28/09/2023 | Start 1e semester
| Aankoop materiaal | Eerste drie weken
| Ontwerpen PCB | Eerste drie weken
| Programmeren MCU | Continu
| Ontwerpen behuizing | Tweede maand
| Dataverwerking ontwerpen | Tweede maand
| Testen opstelling | Laatste twee weken
| LoRa netwerk uitbreiden | Eerste paar dagen
| Sensoren monteren | Eerste paar dagen
| Communicatie testen | Continu
21/12/2023 | Einde 1e semester
N/A | Deadline IoT project

Omschrijving

Autonomie en powermanagement
| Onderzoek hoe batterijstatus bepalen?
| Power mode in de MCU instellen

Ontwikkeling moederbord
| Onderzoek componenten
| Componenten bestellen
| Schema ontwerpen
| Schakeling testen
| Design maken
| PCB bestellen
| PCB bestukken

Communicatie en netwerk
| Uitbreiding LoRaWan netwerk in Hobokense polder (gateway, antennes)
| Test The Things Network

Sturing/MCU programmeren
| Lezen
| | Data sensoren
| | Batterijstatus
| Ingelezen data verzenden
| Waarschuwingen en foutmeldingen
| | Lage batterij
| | Errors opvangen
| Luisteren naar inkomende commando’s

Behuizing en interface
| Fysieke interface
| Behuizing ontwerpen
| | Materiaalkeuze
| | Prototype
| | Ontwikkeling

## Functioneel design

De monitors moeten tegen de regen kunnen en tegelijk lucht doorlaten. We zouden met heel fijne gaasjes kunnen werken die enkel lucht doorlaten en geen waterdruppels, door de oppervlaktespanning van het gaas en de aanwezigheid van waterstofbruggen. Het eenvoudigst is gaten maken in de onderkant van de behuizing waardoor het water langs de zijkanten wegloopt en nooit bij de componenten kan komen.

Daarbij moet het gebruikte materiaal UV-lichtbestendig zijn en over een monteermogelijkheid beschikken. Onze behuizing hangt echter af van de ontwikkeling van het PCB en omgekeerd. We ontwerpen deze dus tijdens de ontwikkelingsfase. De montagetechniek hangt ook sterk af van de locatie in Hobokense polder waar de monitor komt te hangen. Deze zal mogelijks dus ter plaatse nog aangepast moeten worden.

Als uitbreiding tijdens de ontwikkeling kunnen er knoppen of displays worden gemaakt aan de behuizing voor fysieke interactie en snelle debugging.


Figuur 1 dataflow diagram


Figuur 2 Activity diagram


Figuur 3 Blokdiagram

## Technisch design

Smart Object (hardware-analyse)

Bij het doornemen van de documentatie van de printplaat is er vastgesteld dat er voor de ESP al een schakeling is ontworpen voor het ‘connector board’. We zullen de schakeling doornemen de opties die ze gekozen hebben overwegen en indien nodig vervangen.


Energie en powermanagement

Figuur 4 Aansluiting van de voeding op ESP

De ESP is voorzien van een schakeling om de voeding juist aan te sluiten op de ESP. Dit kan via de USB-poort of via de Vin pin. Het bordje opereert op een spanning van 3,3V. Volgens de datasheet van de ESP mag de spanning tussen 1,62V en 3,63V variëren. Dit is ook de spanning die op de I/O pinnen kan komen. Door de aanwezigheid van een voltage regulator (LD1117) kunnen we aan Vin spanningen tot 15V aanleggen en zal de uitgangsspanning 3,3V blijven.

Om de monitors van stroom te voorzien moeten we een zonnepaneel en een batterij gebruiken zodat ze autonoom kunnen werken. Voor het ‘connector board’ van het vorige project werden volgende onderdelen gekozen: een DFR0559 (5V Solar power manager), een 3,7V Li-polymeer of Li-ion batterij, en een zonnepaneel die we tijdens de testfase kunnen vervangen met een micro USB-oplader (5V, 1A). De gemaakte keuzes zullen worden behouden. We willen wel het belang van de kwaliteit van het zonnepaneel benadrukken. Er zijn zonnepanelen van PET beschikbaar maar bij blootstelling aan >1800h UV treedt er UV-degradatie op. UTFE, urethaan of glas zijn betere alternatieven.

In onderstaande figuur is er aangegeven hoe we het zonnepaneel, de batterij en de Solar Power Manager met de printplaat gaan verbinden. De 5V en GND pinnen op de bovenkant van het bord worden naar een LDL1117S33R spanningsstabilisator getrokken die de spanning stabiliseert en doorgeeft aan de sensoren.

Solar Power Manager 5V Connection Diagram

Figuur 5: Verbinding van de energievoorziening

## Componentenlijst:

Component | # nummer | Link
LoRa Chip | esp32 | SX1276 | https://jlcpcb.com/partdetail/Vollgo-SX1276S8S_TX1/C718834
Esp32 MCU | ESP32-WROOM-32-N8 | https://jlcpcb.com/partdetail/EspressifSystems-ESP32_WROOM_32N8/C529582
Zonnepaneel | 110X80 | Aanwezig op school
Solar power manager | DF robot | DFR0559 | https://www.dfrobot.com/product-1712.html + stand offs
Batterij 3,7V | 45F2232 | https://www.sossolutions.nl/lithium-ion-batterij-3-7v-1200mah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
Milieu sensor | SEN55 | https://www.sensirion.com/products/catalog/SEN55
Stikstof sensor | SGP41 | https://sensirion.com/products/catalog/SGP41
USB --> UART | CP2102N | https://jlcpcb.com/partdetail/SILICONLABS-CP2102N_A02GQFN24/C1550551
Testboard | ESP32-dev-board | https://www.tinytronics.nl/shop/en/development-boards/microcontroller-boards/with-wi-fi/esp32-wifi-and-bluetooth-board-cp2102
Wartel | | Voor zonnepaneel kabel
Antenne LoRa 868MHz | | https://www.digikey.be/nl/products/detail/pycom-ltd./SIGFOX%2FLORA%2520ANTENNA%2520KIT/7721843?productid=7721843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
Installatie doos | Z74H | https://www.tinytronics.nl/shop/en/tools-and-mounting/enclosures/universal/kradex-enclosure-176x126x57mm-ip65-red-transparent-z74h

- Op PCB --> blauw | Wordt besteld op het PCB via JLCPCB
- Bestellen -> Groen | Opmerking: DevKits voor ontwikkeling indien mogelijk. (Niet SVM41, losse SGP, losse SEN)
- Aanwezig op school -> Oranje | ESP32 T-Beam nog gaan halen. 5 DFRobots aanwezig.

Eerste prototype:


## Smart object (software-analyse)

Meten en zenden


Figuur 6 zenden en meten

## Teststrategie

Nauwkeurigheid sensoren:

We kunnen na gaan of onze sensoren nauwkeurig zijn door deze te vergelijken met een kwaliteitsvolle meters. Indien niet kunnen wij deze bij kalibreren zodat ze aan de norm voldoen. Hier een lijst met de volgende meettoestellen die we hiervoor kunnen gebruiken.

- Co2 meter

https://www.vtn.nl/product/bw-solo-wireless/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

- Nox meter

https://www.twobtech.com/model-405-nm-nox-monitor.html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

Simulatie (klimaat) omstandigheden:

Doormiddel van simuleren van omstandigheden kunnen we nagaan of de pcb/enclosure tegen de omstandigheden kunnen waar in het geplaats zal worden.

Stabiliteit testen:

Stabiliteit testen zijn noodzakelijk om kwaliteit en levensduur te garanderen. Doormiddel van langdurige testen op zowel op ontvangst van signalen en batterij capaciteit. Hierdoor kunnen we nagaan of deze opstelling langdurig kan blijven werken, en wat of waar onze zwakkepunten zijn.

Communicatie

Het LoRa-netwerk gaan we gebruiken met het ‘The Things Network’ (TTN). The Things Network is een LoRaWAN-netwerk-server voor de deployment van LoRa-applicaties.

## Beschrijving van eventuele datamigratie

Zie functioneel design: data flow diagram.

Onderstaande figuur is een weergave van hoe we de communicatie kunnen aanpakken.

The Things Network Plugin - Thinger.io Documentation

Figuur 7 Blokdiagram: Weergave van de communicatiestructuur

## Beschrijving van eventuele impact op de huidige infrastructuur

De volledige impact op de huidige infrastructuur zullen de vijf monitors zijn, met daarbij een LoRaWAN gateway.

## Analyse van security en eventuele autorisatierollen

In principe is de data die de monitors verzenden geen gevoelige informatie. Informatie over de luchtkwaliteit is geen probleem. Op dit moment is er dus geen noodzaak voor encryptie van de draadloos verstuurde data.

Bij de database-server moet er wel authenticatie voorzien worden zodat alleen gemachtigde gebruikers toegang hebben tot de database. Ook het aanpassen van de configuratie van de gateways en de monitors, evenals misschien het opvragen van data, mag enkel door gemachtigde gebruikers uitgevoerd worden.

## Documentatie

We maken twee verschillende dingen. De eerste is een documentatie van de werking van de monitors en alles dat op de backend gebeurt. Ten tweede voorzien we een handleiding voor het gebruiken en instellen van de monitors. Dit houdt ook de uitleg over de software in. Als we onze documentatie eerst in markdown schrijven kunnen we een gitbook voorzien.

Bij het schrijven van de code van de MCU proberen we op een propere en duidelijke manier te werken. Er worden voldoende uitleg in commentaar in de code geschreven.

2 Blueprint voor project “Luchtkwaliteit Hoboken”

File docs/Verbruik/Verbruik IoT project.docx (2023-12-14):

Verbruik IoT project


Opstart & IDLE – met SEN55

100 – 110 mA

SLEEP

15 – 16 mA

TRANSMIT

PIEK – 260 – 272 mA

SENDING (7 seconds) – 150 – 170 mA


https://infocenter.nordicsemi.com/pdf/PPK2_User_Guide_v1.0.1.pdf

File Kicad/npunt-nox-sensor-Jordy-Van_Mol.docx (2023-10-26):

Front


Back


Isometrische projectie


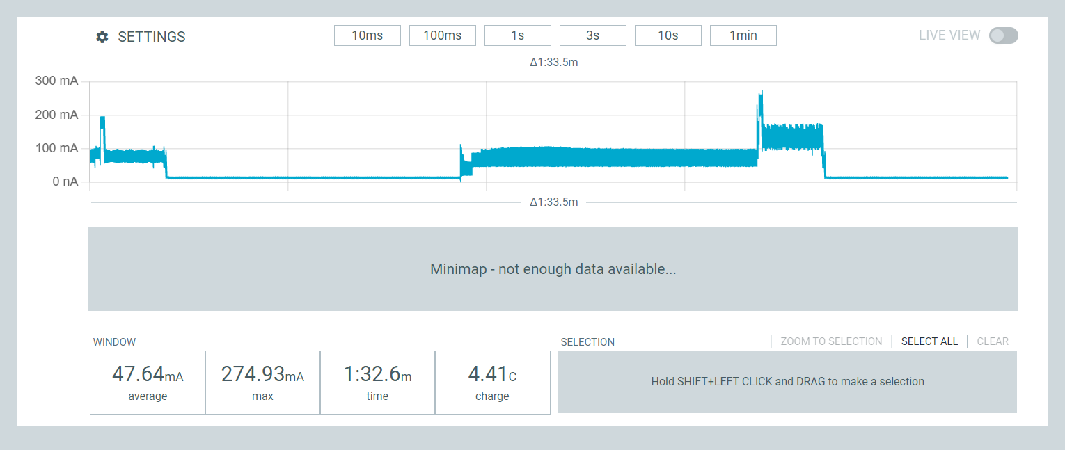
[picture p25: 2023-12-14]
docs/Verbruik/ppk-20231214T114707.png

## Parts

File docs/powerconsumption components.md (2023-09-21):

# SEN55

idle: 
typisch: 2.6mA - max: 3mA

Measurement-Mode (first 60 seconds):
typisch: 70mA - max: 100mA

# SGP41 VOC&nox sensor

idle:
typisch: 34µA-105µA (3,3V)

conditioning mode:
typisch: 4,2mA - max: 4,6mA (3,3V)

regular:
typisch: 3,0mA - max: 3,4mA (3,3V)

# ESP32-WROOM-32-N8 

- deepsleep -> 10 µA
- power off -> 1 µA
- Hibernation -> 5 µA
- Light-sleep -> 0.8 mA
- Modem-sleep:
  - CPU speed 240MHz:
    - dual core -> 30 mA ~ 68 mA
  - CPU speed 160MHz:
    - single core -> 27 mA ~ 44 mA
    - dual core -> 27 mA ~ 34 mA
  - CPU speed 80Hz:
    - single core -> 20 mA ~ 25 mA
    - dual core -> 20 mA ~ 31 mA

# SC1276-7-8

- Sleep mode -> typical 0.2µA, max 1µA
- Idle mode -> 1.5 1µA
- recieving mode -> 12mA
- transmit mode 
  - +20 dBm -> 120mA
  - +17 dBm -> 87mA
  - +13 dBm -> 29mA
  - +7 dBm -> 20mA

# totaal:
idle: 105µA + 3mA
Active: 3,4mA + 100mA

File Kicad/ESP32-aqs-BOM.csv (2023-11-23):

Id | Designator | Footprint | Quantity | Designation | Supplier and ref | Aanwezig in labo | link jlcpcb | jlcpcb part nr | Link leverancier
1 | H2,H4 | MountingHole_2.2mm_M2_ISO7380_Pad | 2 | MountingHole
2 | R5,R2,R4 | R_0805_2012Metric_Pad1.20x1.40mm_HandSolder | 3 | 4k7 |  | J
3 | IC1 | QFN50P400X400X80-25N | 1 | CP2102N-A02-GQFN24 |  | X | https://jlcpcb.com/partdetail/SiliconLabs-CP2102N_A02GQFN20R/C969913 | C969913
4 | U3 | XDCR_SGP41-D-R4 | 1 | SGP41-D-R4 |  | J | (https://jlcpcb.com/partdetail/SensirionAg-SGP41_DR4/C3659325) | C3659325 | https://be.farnell.com/sensirion/sgp41-d-r4/gas-sensor-digital-dfn-6/dp/3858683?st=SGP41-D-R4
5 | C8,C1 | C_0805_2012Metric_Pad1.18x1.45mm_HandSolder | 2 | 100nF |  | J
6 | D1,D2,D3 | LED_0805_2012Metric_Pad1.15x1.40mm_HandSolder | 3 | LED |  | J
7 | J3 | U.FL_Molex_MCRF_73412-0110_Vertical | 1 | ufl connector |  | J |  |  | https://www.digikey.be/en/products/detail/molex/0734120110/1894611
8 | C5,C4,C9,C3,C10 | C_0805_2012Metric_Pad1.18x1.45mm_HandSolder | 5 | 1µF |  | J
9 | R1 | R_0805_2012Metric_Pad1.20x1.40mm_HandSolder | 1 | 1kΩ |  | J
10 | SW1,SW2 | SW_PUSH_6mm | 2 | TC-1102-B-C-B |  | X | https://jlcpcb.com/partdetail/XkbConnectivity-TC_1102_C_BB/C381024 | C381024
11 | R8,R9 | R_0805_2012Metric_Pad1.20x1.40mm_HandSolder | 2 | 1k |  | J
12 | U2 | MODULE_ESP32-WROOM-32 | 1 | ESP32-WROOM-32 |  | X | https://jlcpcb.com/partdetail/EspressifSystems-ESP32_WROOM_32N8/C529582 | C529582 | https://www.digikey.be/nl/products/detail/espressif-systems/ESP32-WROOM-32-N8/9381712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
13 | C7,C14,C12,C11 | C_0805_2012Metric_Pad1.18x1.45mm_HandSolder | 4 | 0.1µF |  | J
14 | U4 | SX1276S8S+T-X1 | 1 | SX1276S8S+T-X1 |  | X | https://jlcpcb.com/partdetail/Dreamlnk-DL_RFM95868M/C2844472 | C2844472 | https://be.farnell.com/hoperf/rfm95w-868s2/transceiver-868mhz-fsk-ook/dp/2759294?st=rfm95
15 | TP1 | TestPoint_THTPad_1.0x1.0mm_Drill0.5mm | 1 | VDD
16 | J1 | GCT_USB4085-GF-A_REVA4 | 1 | USB4085-GF-A_REVA4 |  | X
17 | J2 | JST_BM06B-GHS-TBT_LF__SN__N_ | 1 | JST connector SEN55 |  | X | https://jlcpcb.com/partdetail/207057-BM06B_GHS_TBT_LF_SN_N/C189892 | C189892
18 | D4 | SOD-123FL | 1 | D_Schottky |  | X
19 | J4 | TerminalBlock_Phoenix_MPT-0,5-6-2.54_1x06_P2.54mm_Horizontal | 1 | UART Connector |  | X | https://jlcpcb.com/partdetail/Cixi_KefaElec-KF128_2_546P/C474924 | C474924 | https://www.digikey.be/nl/products/detail/jst-sales-america-inc/BM06B-GHS-TBT-LF-SN-N/807804
20 | R7 | R_0805_2012Metric_Pad1.20x1.40mm_HandSolder | 1 | 47k |  | J
21 | C6,C2,C13 | C_0805_2012Metric_Pad1.18x1.45mm_HandSolder | 3 | 10µF |  | J
22 | R3 | R_0805_2012Metric_Pad1.20x1.40mm_HandSolder | 1 | 10k |  | J
23 | R6 | R_0805_2012Metric_Pad1.20x1.40mm_HandSolder | 1 | 20k |  | J
24 | U1 | SOT-223-3_TabPin2 | 1 | LD1117S33TR_SOT223 |  | X | https://jlcpcb.com/partdetail/Stmicroelectronics-LD1117S33TR/C86781 | C86781 | https://www.digikey.be/nl/products/detail/stmicroelectronics/LD1117S33TR/585766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

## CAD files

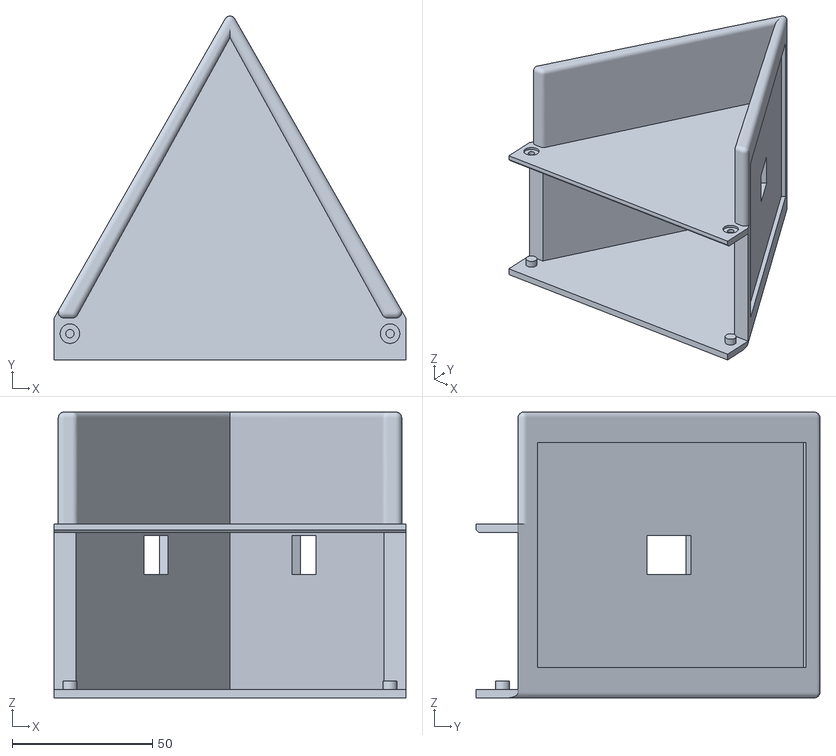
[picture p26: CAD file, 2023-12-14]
Fusion/RoofWireBoxAirQualityHoboken v4.stl
125.4 x 122.7 x 102.0

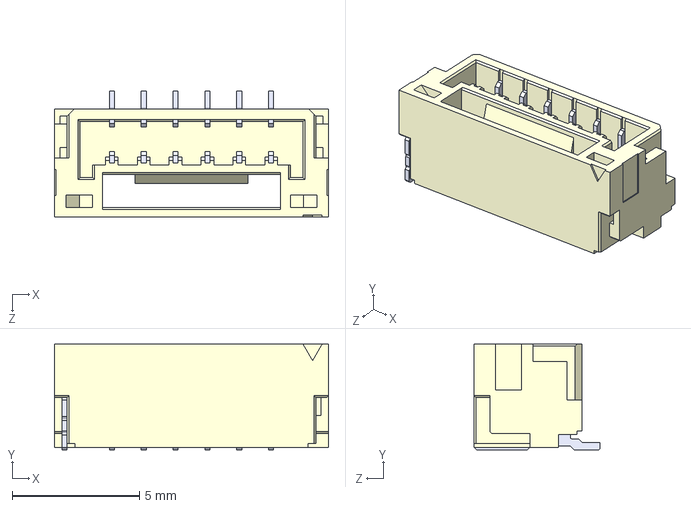
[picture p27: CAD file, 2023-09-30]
Kicad/footprints en symbolen/BM06B-GHS-TBT_LF__SN__N_/BM06B-GHS-TBT_LF__SN__N_.step
10.8 x 4.15 x 4.95 mm

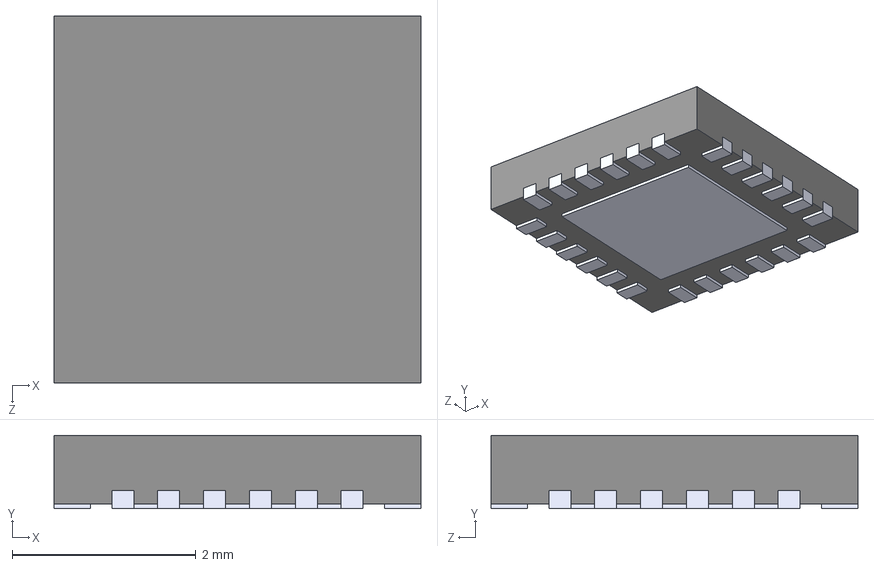
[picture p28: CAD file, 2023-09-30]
Kicad/footprints en symbolen/CP2102N-A02-GQFN24/CP2102N-A02-GQFN24.step
4.00 x 0.8 x 4.00 mm

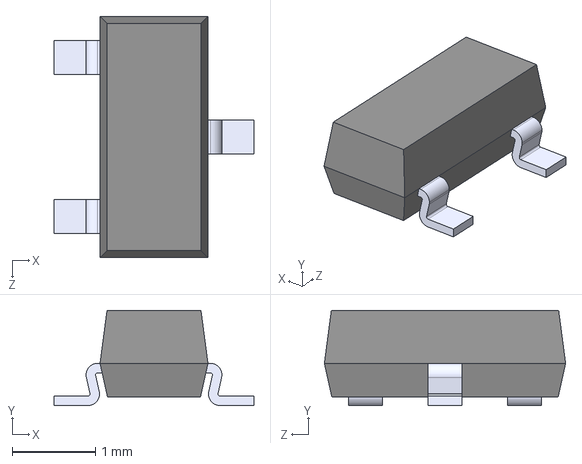
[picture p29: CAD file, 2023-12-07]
Kicad/footprints en symbolen/SS8050-G/SS8050-G.step
2.40 x 1.14 x 2.90 mm

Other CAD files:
Fusion/BackplateAirQualityHoboken v7.f3d
Fusion/BackplateAirQualityHoboken.f3d
Fusion/BackplateAirQualityHoboken_updated.f3d
Fusion/RoofWireBoxAirQualityHoboken v4.f3d

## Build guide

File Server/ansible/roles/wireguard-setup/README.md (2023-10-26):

Role Name
=========

This role sets up a Wireguard server and its configuration file. The Wireguard configuration is compatible with 2 peers.

Role Variables
--------------

wireguard_server_address: the address the server uses to be accessible through the Wireguard tunnel.
allowed_ips1: the range of IPs that are allowed through the tunnel from the first peer.
allowed_ips2: the range of IPs that are allowed through the tunnel from the second peer.
listen_port: the port the server listens on.

Example Playbook
----------------
  vars:
    wireguard_server_address: "10.50.50.1/24"
    allowed_ips1: "10.50.50.2"
    allowed_ips2: "10.50.50.3"
    listen_port: 2709
  roles:
     - role: wireguard-setup

Author Information
------------------

Made by Van Loon Bernd (GitHub: BerrieV1)

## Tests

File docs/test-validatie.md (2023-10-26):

## Vergelijking communicatie AP – Hobokense Polder

De dekking in zowel AP als de Hobokense polder ziet er redelijk goed uit. Op de campus hebben we nog geen probleem gehad met de dekking. Tijdens het bezoek naar de Hobokense Polder hebben we gemerkt dat we gedurende 20 min geen data meer aankregen. We zien das dat de dekking in de Hobokense polder niet zo goed is als op AP, hier gaan we dus rekening mee moeten houden bij het plaatsen van onze sensoren.

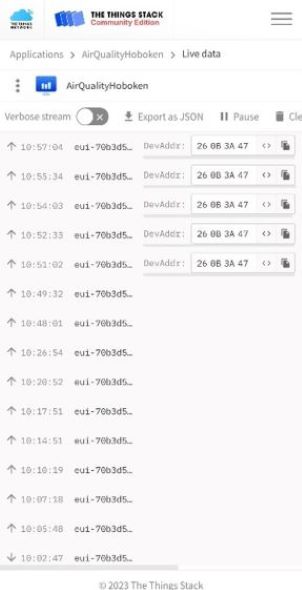
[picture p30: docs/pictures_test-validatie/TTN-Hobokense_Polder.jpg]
Hobokense Polder TTN HP

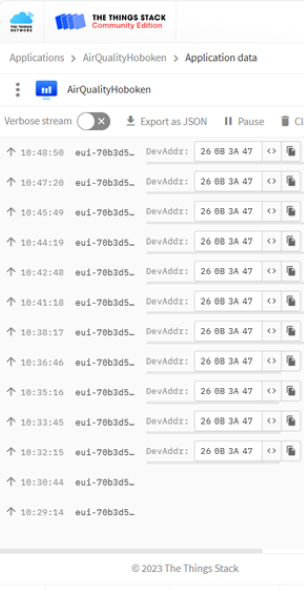
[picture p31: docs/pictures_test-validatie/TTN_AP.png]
AP TTN AP


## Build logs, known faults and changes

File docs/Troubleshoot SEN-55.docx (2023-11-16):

# Probleem

We merken dat bij het testen van de code, de sensor maar 1 keer zijn waardes via LoraWAN doorstuurt, en door een onverklaarbare reden doet hij dit nadien niet meer (bij de volgende uitlezing van de sensor) … Hiervoor hebben we de volgende troubleshoot manieren gevolgd. Zodat we dit probleem succesvol kunnen oplossen.

# Met SDR troubleshooten

Aangezien hij volgens de code wel een lora signaal zou versturen maar deze komt niet aan (in thethingsnetwork) wilde we na gaan of de LoraWAN chip wel werkelijk iets verstuurd als we zenden. Hiervoor hebben we gebruik gemaakt van een SDR met CubeSDR software, zo kunnen we nagaan of het LoraWAN signaal wel in het spectrum verstuurd wordt.

## Resultaten van troubleshoot

Bij het uploaden (opstarten) van de sensor krijgen wij 1 pakket binnen die wij ook kunnen zien via een SDR.

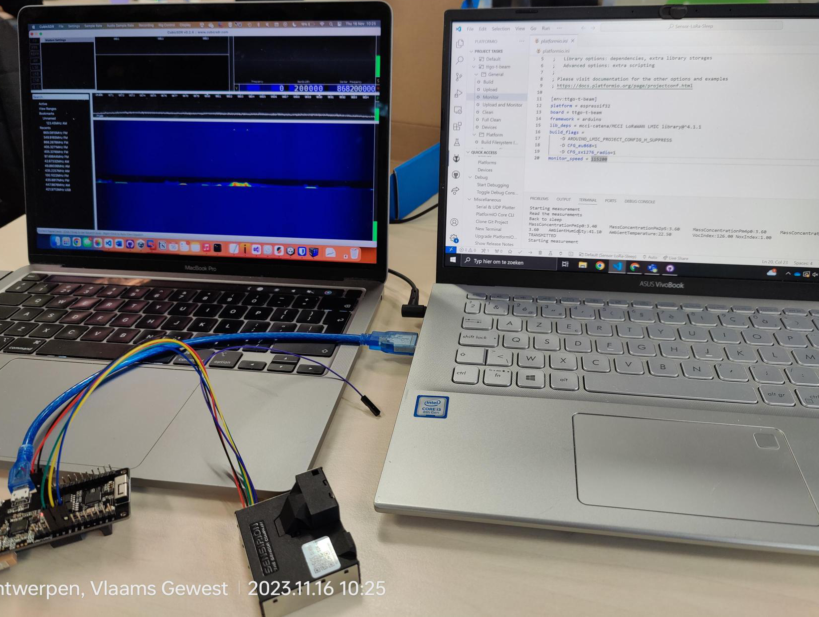
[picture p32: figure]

Hierna gaat de sensor in slaap en bij het ontwaken doet deze weer een meting en verzend deze niet meer.

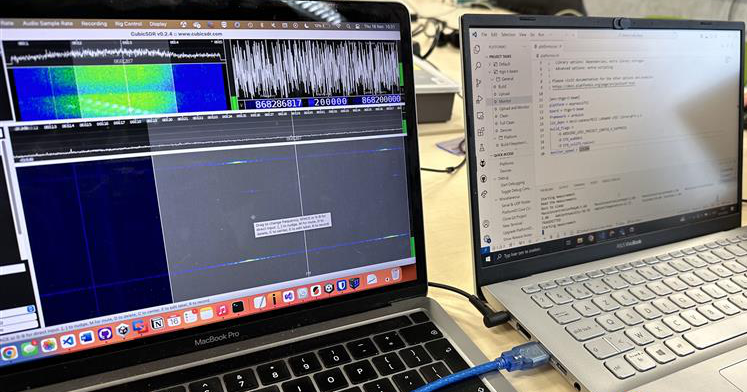
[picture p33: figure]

## TTN

Bij TTN krijgen wij soms het eerste pakketje binnen maar dit resulteert in 00 00 waarde.

0x00, 0x00, 0x00, 0x00, 0x00, 0x00, 0x00, 0x00, 0x00, 0x00, 0x00, 0x00, 0x00, 0x00, 0x00, 0x00

Om een random tijd krijgen wij nu 00 00.

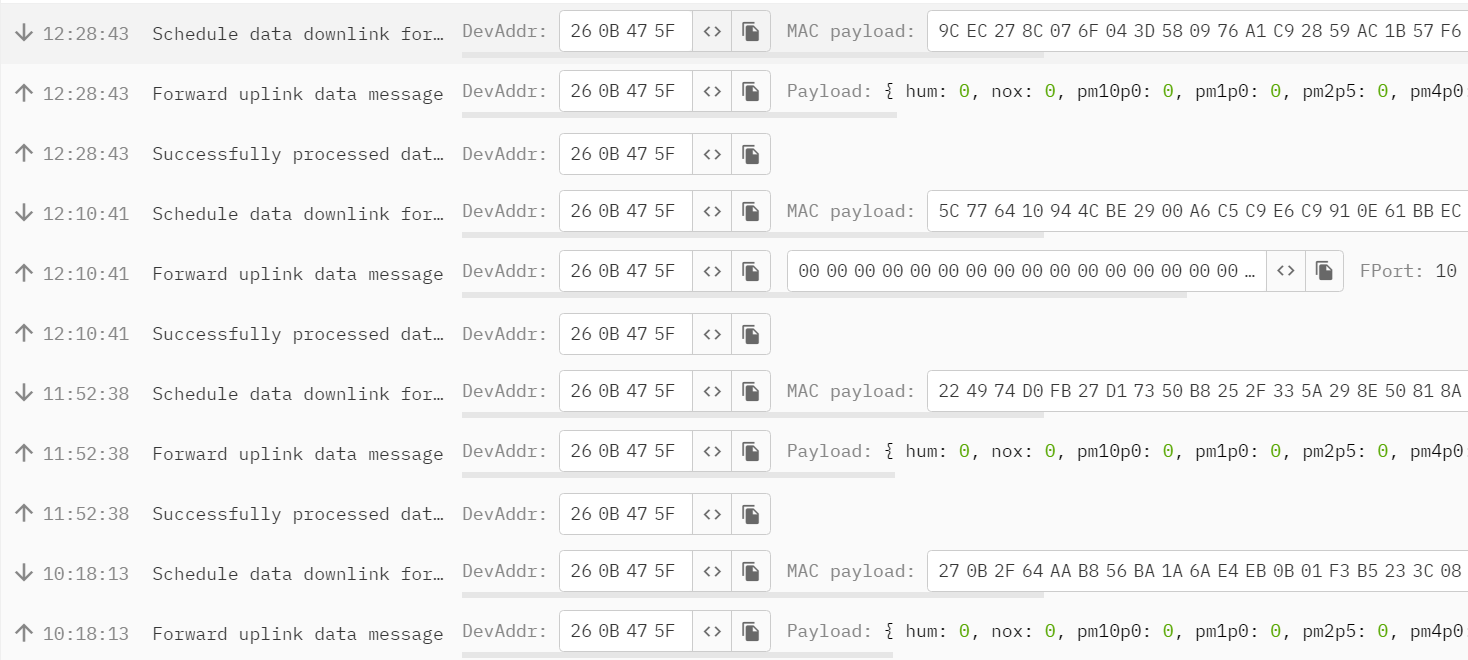
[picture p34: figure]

# Console

Starting measurement

Read the measurements

Back to sleep

MassConcentrationPm1p0:2.60 MassConcentrationPm2p5:2.80 MassConcentrationPm4p0:2.80 MassConcentrationPm10p0:2.80 AmbientHumidity:32.65 AmbientTemperature:25.47 VocIndex:85.00 NoxIndex:1.00

TRANSMITTED

Starting measurement

# Oplossing

uint32_t pm1p0, pm2p5, pm4p0, pm10p0, hum, temp, voc, nox;

* * *

pm1p0 = massConcentrationPm1p0 * 100;

pm2p5 = massConcentrationPm2p5 * 100;

pm4p0 = massConcentrationPm4p0 * 100;

pm10p0 = massConcentrationPm10p0 * 100;

hum = ambientHumidity * 100;

temp = (ambientTemperature + 10) * 100;

voc = vocIndex * 100;

nox = noxIndex * 100;

uint32_t data[8] = { pm1p0, pm2p5, pm4p0, pm10p0, hum, temp, voc, nox };

for (byte i = 0; i < 8; i++) {

//Serial.print(data[i], HEX);

txBuffer[0+i*2] = (data[i] >> 8) & 0xFF;

txBuffer[1+i*2] = (data[i]) & 0xFF;

}

De lijn waarbij we de waardes invullen in de lijst stond voor dat de waardes erin werden gestoken. Dit resulteerde in lege Txbuffer. Dit is opgelost door de waardes uit te printen en zien tot waar de waardes leeg waren

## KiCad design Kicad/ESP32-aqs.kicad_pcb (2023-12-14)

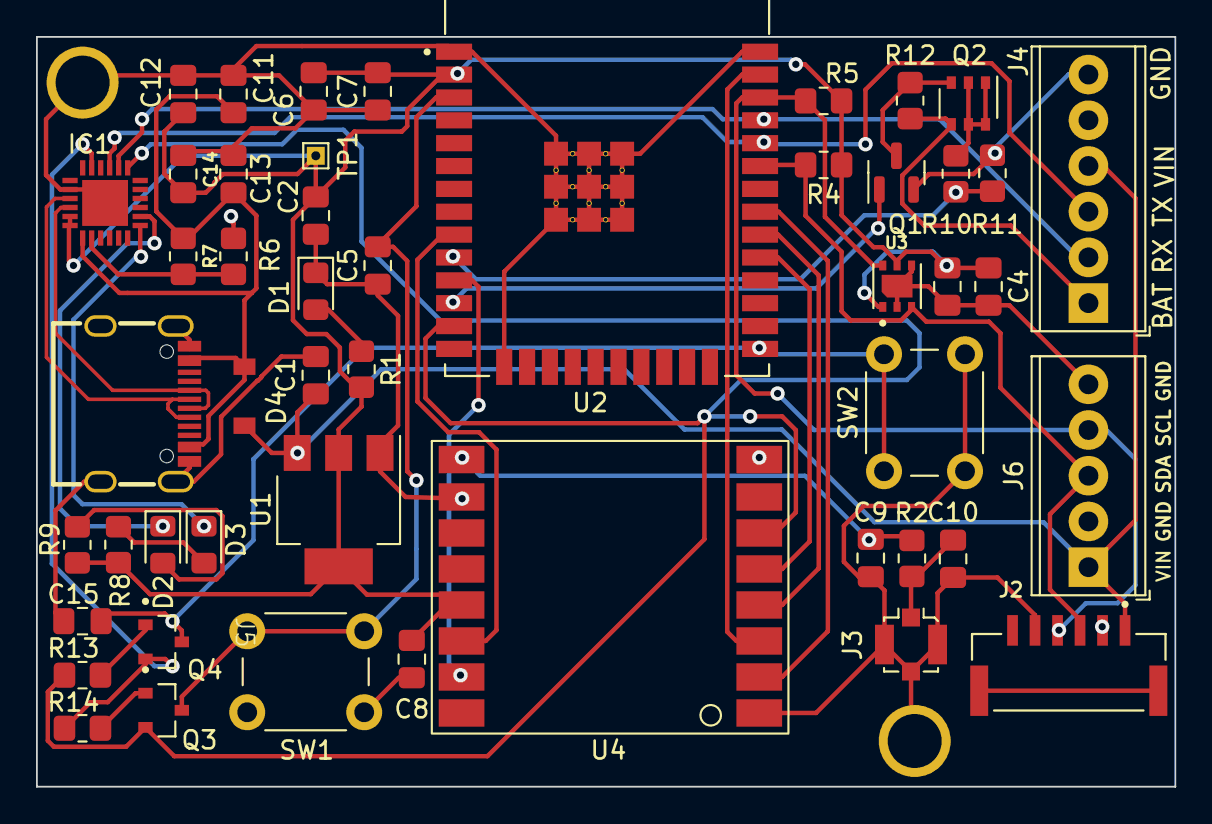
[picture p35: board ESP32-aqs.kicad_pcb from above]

Board: 2 copper layers, 63.2 x 41.7 mm, 51 parts (0 on the bottom side), 35 nets.

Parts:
C1, C8: 100nF; C_0805_2012Metric_Pad1.18x1.45mm_HandSolder
C2, C6, C13: 10µF; C_0805_2012Metric_Pad1.18x1.45mm_HandSolder
C3, C4, C9, C10: 1µF; C_0805_2012Metric_Pad1.18x1.45mm_HandSolder
C5, C7, C11, C12, C14, C15: 0.1µF; C_0805_2012Metric_Pad1.18x1.45mm_HandSolder
D1, D2, D3: LED; LED_0805_2012Metric_Pad1.15x1.40mm_HandSolder
D4: D_Schottky; SOD-123FL
H1, H2: MountingHole_Pad; MountingHole_2.2mm_M2_ISO7380_Pad
IC1: CP2102N-A02-GQFN24; QFN50P400X400X80-25N
J2: JST connector SEN55; JST_BM06B-GHS-TBT_LF__SN__N_
J3: ufl connector; U.FL_Molex_MCRF_73412-0110_Vertical
J4: UART Connector; TerminalBlock_Phoenix_MPT-0,5-6-2.54_1x06_P2.54mm_Horizontal
J5: USB-TYPE-C-018
J6: test point / jst connector; TerminalBlock_Phoenix_MPT-0,5-5-2.54_1x05_P2.54mm_Horizontal
Q1: IRLML0030; SOT-23
Q2: PMN48XP; TSOP-6_1.65x3.05mm_P0.95mm
Q3, Q4: SS8050-G; TRANS_SS8050-G
R1, R8, R9: 1k; R_0805_2012Metric_Pad1.20x1.40mm_HandSolder
R2, R4, R5: 4k7; R_0805_2012Metric_Pad1.20x1.40mm_HandSolder
R6: 20k; R_0805_2012Metric_Pad1.20x1.40mm_HandSolder
R7: 47k; R_0805_2012Metric_Pad1.20x1.40mm_HandSolder
R10, R11: 100k; R_0805_2012Metric_Pad1.20x1.40mm_HandSolder
R12: 1M; R_0805_2012Metric_Pad1.20x1.40mm_HandSolder
R13, R14: 10k; R_0805_2012Metric_Pad1.20x1.40mm_HandSolder
SW1, SW2: TC-1102-B-C-B; SW_PUSH_6mm
TP1: VDD; TestPoint_THTPad_1.0x1.0mm_Drill0.5mm
U1: LD1117S33TR_SOT223; SOT-223-3_TabPin2
U2: ESP32-WROOM-32; MODULE_ESP32-WROOM-32
U3: SGP41-D-R4; XDCR_SGP41-D-R4
U4: SX1276S8S+T-X1

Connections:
+3V3: C2.1, C3.1, C4.1, C6.1, C7.1, C8.1, C12.1, C14.1, IC1.5 (VIO), IC1.6 (VDD), R1.2, R4.1, R5.1, R8.1, R9.1, TP1.1, U1.2 (VO), U2.2 (3V3), U3.1 (VDD), U3.5 (VDDH), U4.13 (VCC)
ANT: C9.2, R2.1, U4.9 (RF)
BAT: J4.1, Q2.4 (S), R12.1
BOOT: C15.1, Q4.3, SW2.1, U2.25 (IO0)
CS: U2.29 (IO5), U4.5 (NSS)
D+: IC1.3 (D+), J5.A6 (DP1), J5.B6 (DP2)
D-: IC1.4 (D-), J5.A7 (DN1), J5.B7 (DN2)
DIO0: U2.9 (IO33), U4.14 (DIO0)
DIO1: U2.11 (IO26), U4.15 (DIO1)
DTR: IC1.23 (DTR), Q4.2, R14.1
EN: C5.1, Q3.3, SW1.2, U2.3 (EN)
GND: C1.2, C2.2, C3.2, C4.2, C5.2, C6.2, C7.2, C8.2, C9.1, C10.1, C11.2, C12.2, C13.2, C14.2, C15.2, D1.1 (K), H1.1, H2.1, IC1.2 (GND_1), IC1.25 (GND_2), J2.2, J2.5, J3.2 (Ext), J4.6, J5.0 (SH), J5.1 (SH), J5.2 (SH), J5.3 (SH), J5.A1 (GND), J5.A12 (GND), J5.B1 (GND), J5.B12 (GND), J6.2, J6.5, Q1.2 (S), R7.2, R11.2, SW1.1, SW2.2, U1.1 (GND), U2.1 (GND), U2.15 (GND), U2.38 (GND), U2.39_1 (GND), U2.39_2 (GND), U2.39_3 (GND), U2.39_4 (GND), U2.39_5 (GND), U2.39_6 (GND), U2.39_7 (GND), U2.39_8 (GND), U2.39_9 (GND), U2.39_10 (GND), U2.39_11 (GND), U2.39_12 (GND), U2.39_13 (GND), U2.39_14 (GND), U2.39_15 (GND), U2.39_16 (GND), U2.39_17 (GND), U2.39_18 (GND), U2.39_19 (GND), U2.39_20 (GND), U2.39_21 (GND), U3.2 (VSS), U3.4 (N/A), U3.7 (EXP), U4.1 (GND), U4.8 (GND), U4.10 (GND)
MISO: U2.31 (IO19), U4.2 (SO)
MOSI: U2.37 (IO23), U4.3 (SI)
unnamed: D1.2 (A), R1.1
unnamed: D2.2 (A), R9.2
unnamed: D3.2 (A), R8.2
unnamed: IC1.8 (VBUS), R6.2, R7.1
unnamed: C10.2, J3.1 (In), R2.2
unnamed: Q1.3 (D), Q2.3 (G), R12.2
unnamed: Q2.1 (D), Q2.2 (D), Q2.5 (D), Q2.6 (D), R10.1
unnamed: Q3.1, R14.2
unnamed: Q4.1, R13.2
READ_BAT: Q1.1 (G), U2.12 (IO27)
RST: IC1.19 (RTS), Q3.2, R13.1, U2.13 (IO14), U4.6 (RST)
RX: IC1.20 (RXD), J4.2, U2.35 (TXD0)
RXLED: D3.1 (K), IC1.13 (GPIO.1_/_RXT)
SCK: U2.30 (IO18), U4.4 (SCK)
SCL: J2.4, J6.4, R5.2, U2.36 (IO22), U3.6 (SCL)
SDA: J2.3, J6.3, R4.2, U2.33 (IO21), U3.3 (SDA)
TX: IC1.21 (TXD), J4.3, U2.34 (RXD0)
TXLED: D2.1 (K), IC1.14 (GPIO.0_/_TXT)
VBAT: R10.2, R11.1, U2.10 (IO25)
VBUS: C11.1, C13.1, D4.2 (A), IC1.7 (VREGIN), J5.A4 (VBUS), J5.A9 (VBUS), J5.B4 (VBUS), J5.B9 (VBUS), R6.1
VIN: C1.1, D4.1 (K), J2.1, J4.4, J6.1, U1.3 (VI)

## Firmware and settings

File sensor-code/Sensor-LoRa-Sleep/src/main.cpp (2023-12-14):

#include <Arduino.h>
#include <Wire.h>

#include <SensirionI2CSen5x.h>
#include <lmic.h>
#include <hal/hal.h>

#include "configuration.h"
#include "credentials.h"

#ifdef LORA_DEBUG
#include "lora_debug.h"
#endif

SensirionI2CSen5x sen55;

// These functions are used by OTAA
void os_getArtEui (u1_t* buf) { memcpy_P(buf, APPEUI, 8);}
void os_getDevEui (u1_t* buf) { memcpy_P(buf, DEVEUI, 8);}
void os_getDevKey (u1_t* buf) {  memcpy_P(buf, APPKEY, 16);}

static uint8_t txBuffer[DATA_LENGTH];
static osjob_t sendjob;

// Data to be put in RTC memory; doesn't get deleted in deep sleep
RTC_DATA_ATTR lmic_t RTC_LMIC;
RTC_DATA_ATTR bool senReady = true, gotosleep = false;

// Pin mapping
const lmic_pinmap lmic_pins = {
    .nss = NSS_GPIO,
    .rxtx = LMIC_UNUSED_PIN,
    .rst = RESET_GPIO,
    .dio = {DIO0_GPIO, DIO1_GPIO, DIO2_GPIO},
};

void removePollingState() {
  bit_t lmic_status = LMIC_queryTxReady();
  if (!lmic_status) {
    LMIC.opmode &= ~OP_POLL;
  }
}

void saveLMICToRTC() {
  Serial.println("Saving LMIC to RTC memory");
  RTC_LMIC = LMIC;

  // Compensate availability timer values for each band; else it keeps going up and tx_start interval gets bigger
  unsigned long now = millis();

  for (int i = 0; i < MAX_BANDS; i++) {
    ostime_t correctedAvail = RTC_LMIC.bands[i].avail - ((now / 1000.0 + TX_INTERVAL) * OSTICKS_PER_SEC);
    if (correctedAvail < 0) {
      correctedAvail = 0;
    }
    RTC_LMIC.bands[i].avail = correctedAvail;
  }

  RTC_LMIC.globalDutyAvail = RTC_LMIC.globalDutyAvail - ((now / 1000.0 + TX_INTERVAL) * OSTICKS_PER_SEC);
  if (RTC_LMIC.globalDutyAvail < 0) {
    RTC_LMIC.globalDutyAvail = 0;
  }
}

void loadLMICFromRTC() {
  Serial.println("Loading LMIC from RTC memory");
  LMIC = RTC_LMIC;
}

void doDeepSleep(uint16_t sleepSeconds) {
  Serial.flush();
  esp_sleep_enable_timer_wakeup(sleepSeconds * 1000000); // in µs
  esp_deep_sleep_start();
}

void do_send(osjob_t* j){
  Serial.println("Sending");
  float f_pm1p0, f_pm2p5, f_pm4p0, f_pm10p0, f_hum, f_temp, f_voc, f_nox;

  sen55.readMeasuredValues(
    f_pm1p0, f_pm2p5, f_pm4p0, f_pm10p0, f_hum, f_temp, f_voc, f_nox
  );

  // Convert floats to uints for smaller data size
  // Payload formatter in TTN reverts conversion
  uint32_t u_pm1p0 = f_pm1p0 * 100;
  uint32_t u_pm2p5 = f_pm2p5 * 100;
  uint32_t u_pm4p0 = f_pm4p0 * 100;
  uint32_t u_pm10p0 = f_pm10p0 * 100;
  uint32_t u_hum = f_hum * 100;
  uint32_t u_temp = (f_temp + 10) * 100;
  uint32_t u_voc = f_voc * 100;
  uint32_t u_nox = f_nox * 100;

  uint32_t data[8] = { u_pm1p0, u_pm2p5, u_pm4p0, u_pm10p0, u_hum, u_temp, u_voc, u_nox };

  // Put data in txBuffer
  for (byte i = 0; i < 8; i++) {
    txBuffer[0+i*2] = (data[i] >> 8) & 0xFF;
    txBuffer[1+i*2] = (data[i]) & 0xFF;
  }

  // Prepare upstream data transmission at the next possible time.
  lmic_tx_error_t error = LMIC_setTxData2_strict(LORAWAN_PORT, txBuffer, DATA_LENGTH, 0);
  Serial.print("Error: ");
  Serial.println(error);
  if (error) {
    Serial.println("Error detected, not sending; going to sleep");
    LMIC_reset();
    doDeepSleep(60);
    // Put MCU back to sleep; restarts tx loop, queue new packet afterwards 
  } else {
    // Set spread factor to SF in configuration
    LMIC_setDrTxpow(LORAWAN_SF, 14);
    Serial.println(F("Packet queued"));
    // Next TX is scheduled after TX_COMPLETE event.
  }
}

void onEvent (ev_t ev) {
  switch(ev) {
    case EV_SCAN_TIMEOUT:
      Serial.println(F("EV_SCAN_TIMEOUT"));
      break;
    case EV_BEACON_FOUND:
      Serial.println(F("EV_BEACON_FOUND"));
      break;
    case EV_BEACON_MISSED:
      Serial.println(F("EV_BEACON_MISSED"));
      break;
    case EV_BEACON_TRACKED:
      Serial.println(F("EV_BEACON_TRACKED"));
      break;
    case EV_JOINING:
      Serial.println(F("EV_JOINING"));
      break;
    case EV_JOINED:
      Serial.println(F("EV_JOINED"));
      {
        u4_t netid = 0;
        devaddr_t devaddr = 0;
        u1_t nwkKey[16];
        u1_t artKey[16];
        LMIC_getSessionKeys(&netid, &devaddr, nwkKey, artKey);
        Serial.print("netid: ");
        Serial.println(netid, DEC);
        Serial.print("devaddr: ");
        Serial.println(devaddr, HEX);
        Serial.print("AppSKey: ");
        for (size_t i=0; i<sizeof(artKey); ++i) {
          Serial.print(artKey[i], HEX);
        }
        Serial.println("");
        Serial.print("NwkSKey: ");
        for (size_t i=0; i<sizeof(nwkKey); ++i) {
          Serial.print(nwkKey[i], HEX);
        }
        Serial.println();
      }
      // Disable link check validation (automatically enabled
      // during join, but because slow data rates change max TX
      // size, we don't use it.
      LMIC_setLinkCheckMode(0);
      break;
    case EV_JOIN_FAILED:
      Serial.println(F("EV_JOIN_FAILED"));
      break;
    case EV_REJOIN_FAILED:
      Serial.println(F("EV_REJOIN_FAILED"));
      break;
    case EV_TXCOMPLETE:
      Serial.println(F("EV_TXCOMPLETE (includes waiting for RX windows)"));
      if (LMIC.txrxFlags & TXRX_ACK)
        Serial.println(F("Received ack"));
      if (LMIC.dataLen) {
        Serial.print(F("Received "));
        Serial.print(LMIC.dataLen);
        Serial.println(F(" bytes of payload"));
      }
      // Go to sleep on completion of TX
      gotosleep = true;
      break;
    case EV_LOST_TSYNC:
      Serial.println(F("EV_LOST_TSYNC"));
      break;
    case EV_RESET:
      Serial.println(F("EV_RESET"));
      break;
    case EV_RXCOMPLETE:
      Serial.println(F("EV_RXCOMPLETE"));
      break;
    case EV_LINK_DEAD:
      Serial.println(F("EV_LINK_DEAD"));
      break;
    case EV_LINK_ALIVE:
      Serial.println(F("EV_LINK_ALIVE"));
      break;
    case EV_TXSTART:
      Serial.println(F("EV_TXSTART"));
      break;
    case EV_TXCANCELED:
      Serial.println(F("EV_TXCANCELED"));
      break;
    case EV_RXSTART:
      /* do not print anything -- it wrecks timing */
      break;
    case EV_JOIN_TXCOMPLETE:
      Serial.println(F("EV_JOIN_TXCOMPLETE: no JoinAccept"));
      break;
      
    default:
      Serial.print(F("Unknown event: "));
      Serial.println((unsigned) ev);
      break;
  }
}


void setup() {
  Serial.begin(SERIAL_BAUD);
  while (!Serial);

  // Init communication with sensor
  Wire.begin();
  sen55.begin(Wire);

  // LMIC init
  os_init();
  // Reset the MAC state. Session and pending data transfers will be discarded.
  LMIC_reset();
  // Disable adaptive data rate/adaptive spread factor
  LMIC_setAdrMode(false);

  // Only load LMIC config when planning to send (aka sensor is ready to be read)
  if (RTC_LMIC.seqnoUp && senReady) {
    loadLMICFromRTC();
  }

#ifdef LORA_DEBUG
    LoraWANDebug(LMIC);
#endif

  // Start job (sending automatically starts OTAA too)
  if (senReady) {
    do_send(&sendjob);
  }
}

void loop() {
  if (gotosleep) {
    // Turn off sensor, save LMIC config and put esp in deep sleep
    Serial.println("Stopping sen55");
    sen55.stopMeasurement();
    senReady = false;
    gotosleep = false;
    removePollingState();
    saveLMICToRTC();
    doDeepSleep(SLEEP_S);
  } else if (!senReady) {
    // Start sensor and go back to deep sleep waiting for sensor setup time
    Serial.println("Starting sen55");
    sen55.startMeasurement();
    senReady = true;
    doDeepSleep(SENSOR_SETUP_S);
  } else {
    // Check if any jobs are queued; if so, execute job
    os_runloop_once();
  }
}

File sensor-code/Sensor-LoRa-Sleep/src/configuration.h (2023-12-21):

#pragma once

#include <Arduino.h>
#include <lmic.h>

// -----------------------------------------------------------------------------
// Configuration
// -----------------------------------------------------------------------------

#define SERIAL_BAUD    115200                       // Serial debug baud rate
#define DATA_LENGTH    16                           // Size of TX buffer sent over LoRa
#define TX_INTERVAL    1020                         // Seconds between each transmit
#define SENSOR_SETUP_S 120                          // Time needed for sensor to return valid measurements (at least 2 min)
#define SLEEP_S        TX_INTERVAL - SENSOR_SETUP_S // Seconds of deep sleep for ESP32 (= tx_interval - sensor setup time) 
#define LORAWAN_PORT   1                            // Port the messages will be sent to
#define LORAWAN_SF     EU868_DR_SF10                // Spreading factor (recommended DR_SF7 for ttn network map purposes, DR_SF10 works for slow moving trackers)

// -----------------------------------------------------------------------------
// Enable debugging
// -----------------------------------------------------------------------------

// #define LORA_DEBUG

// -----------------------------------------------------------------------------
// LoRa SPI
// -----------------------------------------------------------------------------

#define SCK_GPIO        18
#define MISO_GPIO       19
#define MOSI_GPIO       23
#define NSS_GPIO        5
#define RESET_GPIO      14
#define DIO0_GPIO       33
#define DIO1_GPIO       26  // Note: not really used on this board
#define DIO2_GPIO       32  // Note: not really used on this board

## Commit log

2023-09-21 Kicad Schematics and PCB
    [ESP32-aqs.kicad_pcb, ESP32-aqs.kicad_sch]
2023-09-21 start power consumption
2023-09-21 Update powerconsumption components.md
2023-09-21 power consumption
2023-09-28 Update schematic
    [ESP32-WROOM-32.step, ESP32-aqs.kicad_pcb, ESP32-aqs.kicad_sch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]
2023-09-28 pcb design
    [ESP32-aqs.kicad_pcb]
2023-09-28 Add box enclosure concept
2023-09-28 feat: renamed and added serial print of results
2023-09-28 PCB design update
    [ESP32-aqs.kicad_pcb]
2023-09-28 DEV board + lora shield
    the needed library for the lora shield + example code
2023-10-05 PCB + BoM
    [ESP32-aqs-BoM.csv, ESP32-aqs.csv, ESP32-aqs.kicad_sch]
2023-10-12 Create BackplateAirQualityHoboken v7.f3d
    [BackplateAirQualityHoboken v7.f3d]
2023-10-12 fix: ino to cpp and h for proper imports
    [main.cpp]
2023-10-19 added node-red flow and docker compose
2023-10-19 PCB design geupdate
    [ESP32-aqs-B_Cu.gbl, ESP32-aqs-B_Mask.gbs, ESP32-aqs-B_Paste.gbp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]
2023-10-26 fix: removed double data array
    [main.cpp]
2023-11-16 schematic v2
    [ESP32-aqs.kicad_sch]
2023-11-16 PCB v2
    [ESP32-aqs.kicad_pcb]
2023-11-16 silkscreen aanpassing
    [ESP32-aqs.csv, ESP32-aqs.kicad_pcb]
2023-11-23 AXP removed
    removed AXP module, GPS and all serial.prints
2023-11-23 feat: create lmic lib test
    [configuration.h]
2023-11-23 fix: setup of otaa conn
    [main.cpp]
2023-11-23 chore: remove unused libs
    [configuration.h]
2023-11-23 feat: add config file
    [configuration.h]
2023-11-23 fix: fix everything and add otaa
    [main.cpp]
2023-11-23 chore: add monitor filters
2023-11-23 feat: add constants for sleep
    [configuration.h]
2023-11-26 Added 3d print files for roof
2023-11-30 docs: clarify sleep_ms
    [configuration.h]
2023-11-30 fix: sleep_ms correction
    [configuration.h]
2023-11-30 fix: change from ms to sleep_s
    [configuration.h]
2023-11-30 fix: forgot to start measurement
    [main.cpp]
2023-11-30 updated schematic
    [ESP32-aqs.kicad_sch]
2023-11-30 pcb update
    [ESP32-aqs.kicad_pcb, ESP32-aqs.kicad_sch]
2023-12-07 PCB v3
2023-12-07 chore: add debugging
    [configuration.h]
2023-12-07 comment: explain different parts of code
    [configuration.h]
2023-12-07 fix: try to resolve tx error automatically
    [main.cpp]
2023-12-07 comment: explain sensor_setup_s
    [configuration.h]
2023-12-14 refactor: handle send error by going back to sleep
    [main.cpp]
2023-12-14 PCB 2de versie
    [configuration.h]
2023-12-14 Adde lastest roofbox updates
    [RoofWireBoxAirQualityHoboken v4.f3d, RoofWireBoxAirQualityHoboken v4.stl]
2023-12-14 feat: fix lora getting stuck in polling opmode
    [main.cpp]
2023-12-21 fix: remove unnecessary comma
    [configuration.h]
2023-12-21 Backplate final version
    [BackplateAirQualityHoboken.f3d]
2023-12-21 Added latest node-red flow added latest docker-compose
